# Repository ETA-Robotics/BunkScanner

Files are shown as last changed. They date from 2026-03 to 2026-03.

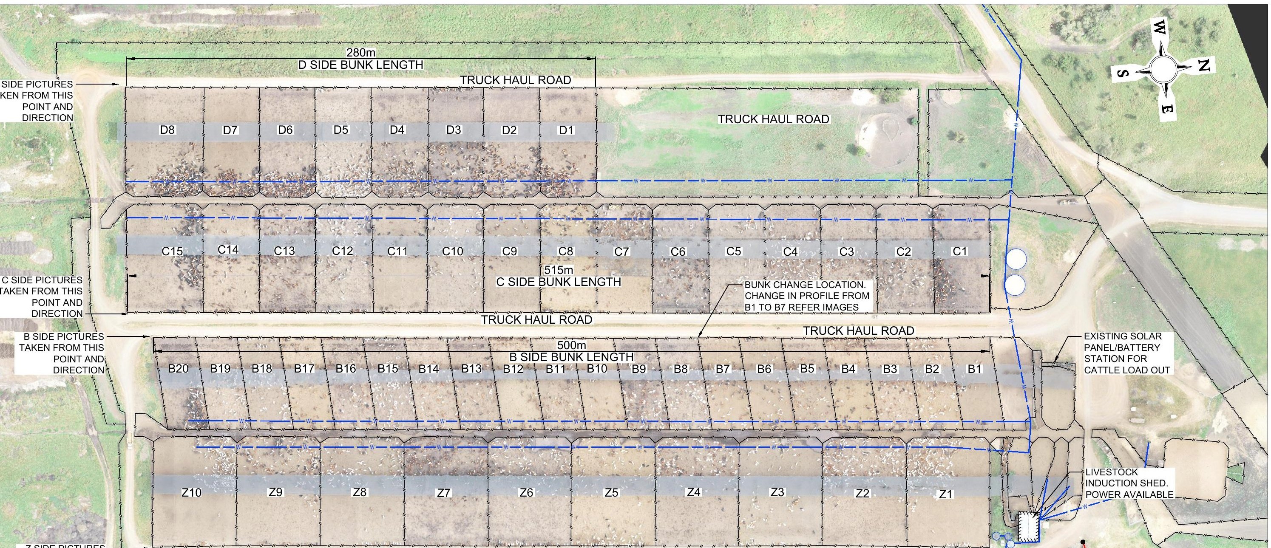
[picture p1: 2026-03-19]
Code/web/feedlot-layout.jpg

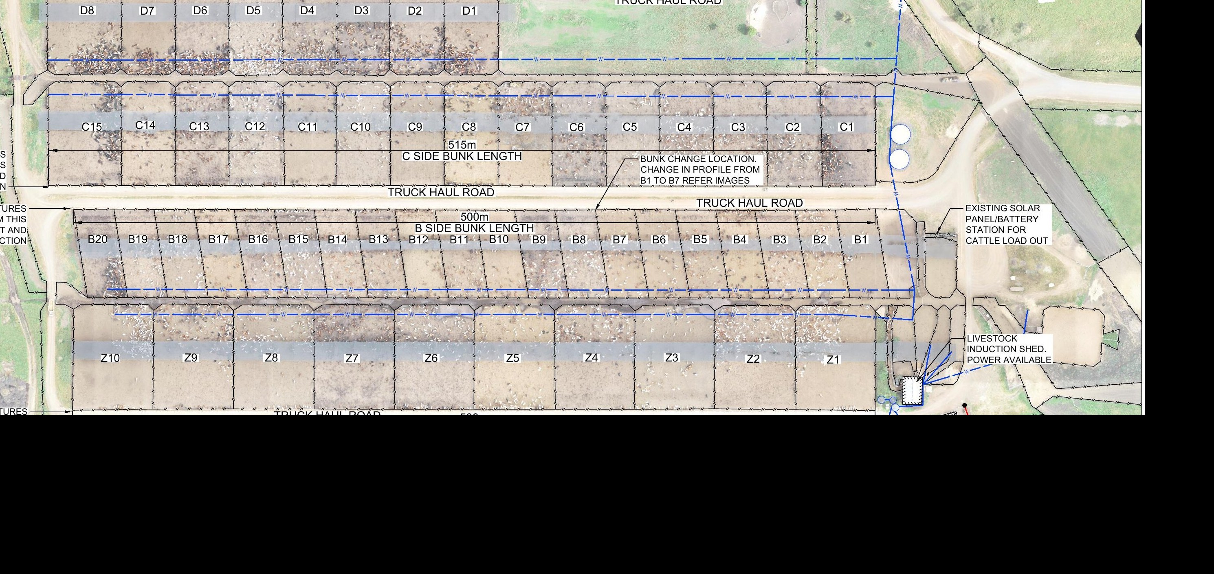
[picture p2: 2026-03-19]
Code/web/feedlot-layout-crop.jpg

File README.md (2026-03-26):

# BunkScanner

Real-time feedlot bunk monitoring system with web-based dashboard for feed level tracking across multiple pen sections. Integrates with Arduino Opta hardware for industrial IoT data collection.

## Overview

BunkScanner provides:
- Real-time feed level monitoring across all pen sections
- Early detection of low feed conditions
- Feed consumption tracking and analytics
- Reduced manual inspection requirements
- Optimized feed distribution scheduling

## System Architecture

### Hardware
- Arduino Opta industrial IoT gateway
- Ultrasonic sensors (4 per 2.4m segment)
- WFLBT02 standard bunks (430mm depth)

### Software
- Web dashboard with SVG layout visualization
- Real-time data processing and alerts
- Development simulation environment

## Monitoring Coverage

The system monitors three main feedlot sections:

**D Side**: 8 pens (D1-D8), 280m total length  
**C Side**: 15 pens (C1-C15), 515m total length  
**B Side**: 20 pens (B1-B20), 500m total length

## Features

- Live feed level visualization with status indicators
- Low feed condition alerts and notifications
- Feed level trends and consumption analytics
- Interactive pen segment inspection
- Mobile-responsive interface
- 30-second data polling intervals

## Technical Specifications

- Segment length: 2.4m per monitored section
- Sensor density: 4 ultrasonic sensors per segment  
- Bunk depth: 430mm internal (WFLBT02)
- Update frequency: 30-second polling
- Layout resolution: 2990 × 1290 pixels

## Installation

### Requirements
- Web server (Apache/Nginx)
- Network access to Arduino Opta
- SVG-compatible web browser

### Setup
1. Deploy repository to web server
2. Configure Arduino Opta network settings
3. Update API endpoints in `Code/web/app.js`
4. Access web interface via server URL

## Project Structure

```
BunkScanner/
├── README.md                           # This file
├── LICENSE                             # Private ETA License
├── Code/                               # Application source code
│   ├── server.js                       # Express server entrypoint
│   ├── tests/                          # Main Jest test suite
│   ├── test/                           # Legacy protocol and API tests
│   ├── firmware/                       # STM32 node and Opta gateway firmware
│   ├── coverage/                       # Jest coverage output
│   ├── lib/                            # Shared backend modules
│   ├── tools/                          # Diagnostic and monitoring CLIs
│   └── web/                            # Web application
│       ├── index.html                  # Main dashboard interface
│       ├── app.js                      # Application logic and data processing
│       ├── style.css                   # User interface styling
│       ├── feedlot-layout.jpg          # Full feedlot overhead layout
│       └── feedlot-layout-crop.jpg     # Cropped layout for UI overlay
└── docs/                               # Planning and project documentation
```

## Usage

1. Access web dashboard
2. Monitor real-time feed levels via color indicators
3. Review alert notifications for low feed conditions
4. Click pen sections for detailed sensor readings
5. Track consumption trends and patterns

## Interface

- Green: Adequate feed levels (>70%)
- Yellow: Moderate feed levels (30-70%)
- Red: Low feed requiring attention (<30%)
- Alert counter shows active low-feed conditions
- Connection indicator displays hardware status

## License & Privacy

Proprietary system containing operational data and monitoring algorithms. Access restricted to authorized personnel and approved evaluation partners under Private ETA License terms.

## Support

Contact ETA Engineering Technologies Australia for technical support and configuration assistance.

---

© 2026 ETA Engineering Technologies Australia. All rights reserved.

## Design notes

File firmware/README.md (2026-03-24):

# BunkScanner Firmware

RS485 Modbus RTU sensor network for feedlot bunk monitoring.

## Architecture

```
┌─────────────────────────────────────────────────────────────────┐
│                        Web Dashboard                            │
│                     (browser, app.js)                            │
└───────────────────────────┬─────────────────────────────────────┘
                            │ HTTP REST
                            ▼
┌─────────────────────────────────────────────────────────────────┐
│                    Node.js Backend Server                        │
│                      (server.js:3000)                            │
└────┬────────┬────────┬────────┬────────┬────────┬────────┬──────┘
     │        │        │        │        │        │        │
     ▼        ▼        ▼        ▼        ▼        ▼        ▼
  Opta #1  Opta #2  Opta #3  Opta #4  Opta #5  Opta #6  Opta #7
  BUS-D    BUS-C1   BUS-C2   BUS-B1   BUS-B2   BUS-Z1   BUS-Z2
     │        │        │        │        │        │        │
     ▼        ▼        ▼        ▼        ▼        ▼        ▼
  ┌──┴──┐  ┌──┴──┐  ┌──┴──┐  ┌──┴──┐  ┌──┴──┐  ┌──┴──┐  ┌──┴──┐
  │~117 │  │~108 │  │~107 │  │~104 │  │~104 │  │~104 │  │~104 │
  │nodes│  │nodes│  │nodes│  │nodes│  │nodes│  │nodes│  │nodes│
  └─────┘  └─────┘  └─────┘  └─────┘  └─────┘  └─────┘  └─────┘
           RS485 daisy-chain, 115200 baud, 24V DC power
```

## Directory Structure

```
firmware/
├── node/                         STM32 sensor node firmware
│   ├── Inc/
│   │   ├── pin_config.h          GPIO/peripheral pin assignments
│   │   ├── modbus_slave.h        Modbus RTU slave API
│   │   ├── vl53l7cx_driver.h     VL53L7CX ToF sensor driver API
│   │   └── auto_address.h        Daisy-chain auto-addressing API
│   ├── Src/
│   │   ├── main.c                Application entry point & peripheral init
│   │   ├── modbus_slave.c        Modbus RTU slave implementation
│   │   ├── vl53l7cx_driver.c     ToF sensor driver (wraps ST ULD)
│   │   └── auto_address.c        Auto-addressing GPIO & flash storage
│   ├── Drivers/                  (add STM32G0 HAL + VL53L7CX ULD here)
│   ├── CMakeLists.txt            CMake build configuration
│   └── STM32G071RBTx_FLASH.ld   Linker script
│
└── gateway/
    └── opta_gateway/
        └── opta_gateway.ino      Arduino Opta gateway sketch
```

## Node Firmware (STM32G071RBT6)

### Prerequisites

1. **ARM GCC Toolchain**: `arm-none-eabi-gcc` (10.3+ recommended)
2. **STM32G0xx HAL**: Download from [ST](https://www.st.com/en/embedded-software/stm32cubeg0.html) and place in `Drivers/`
3. **VL53L7CX ULD**: Download from [ST](https://www.st.com/en/embedded-software/stsw-img036.html) and place in `Drivers/`
4. **CMake**: 3.20+
5. **ST-Link or J-Link**: For flashing

### Building

```bash
cd firmware/node
mkdir build && cd build
cmake -DCMAKE_BUILD_TYPE=Release ..
make -j$(nproc)
```

Output: `bunkscanner_node.hex`, `bunkscanner_node.bin`

### Flashing

```bash
# With ST-Link
st-flash write bunkscanner_node.bin 0x08000000

# With OpenOCD
openocd -f interface/stlink.cfg -f target/stm32g0x.cfg \
        -c "program bunkscanner_node.hex verify reset exit"
```

### Pin Map (LQFP48)

| Function | Pin  | Port | Notes |
|---|---|---|---|
| I2C1 SCL | 42 | PB6 | CAM1+CAM2, 400kHz |
| I2C1 SDA | 43 | PB7 | External 2.2kΩ pull-ups  |
| I2C2 SCL | 21 | PA11 | CAM3+CAM4, 400kHz |
| I2C2 SDA | 22 | PA12 | External 2.2kΩ pull-ups  |
| RS485 TX | 12 | PA2 | USART2 |
| RS485 RX | 13 | PA3 | USART2 |
| RS485 DE | 11 | PA1 | Hardware DE control |
| CAM1 LPn | 26 | PB0 | Sensor enable |
| CAM2 LPn | 27 | PB1 | Sensor enable |
| CAM3 LPn | 28 | PB2 | Sensor enable |
| CAM4 LPn | 29 | PB3 | Sensor enable |
| ADDR_IN | 10 | PA0 | Input, pull-up |
| ADDR_OUT | 14 | PA4 | Open-drain output |
| Status LED | 37 | PC6 | Push-pull |

### Modbus Register Map

| Register | Name | Type | Description |
|---|---|---|---|
| 0 | STATUS | UINT16 | Sensor health bits + node state |
| 1 | CAM1_FILL  | UINT16 | Fill % × 10 (0–1000) |
| 2 | CAM2_FILL  | UINT16 | Fill % × 10 |
| 3 | CAM3_FILL  | UINT16 | Fill % × 10 |
| 4 | CAM4_FILL  | UINT16 | Fill % × 10 |
| 5 | AVG_FILL | UINT16 | Average fill × 10 |
| 6 | VARIANCE | UINT16 | Cross-sensor variance × 10 |
| 7 | CONFIDENCE | UINT16 | Measurement confidence (0–100) |

Custom function codes: `0x41` (assign address), `0x42` (address complete), `0x43` (full zone data)

## Gateway Firmware (Arduino Opta)

### Prerequisites

1. **Arduino IDE** 2.x or **arduino-cli**
2. **Board package**: Arduino Mbed OS Opta Boards
3. **Libraries**: ArduinoRS485, Ethernet, ArduinoJson

### Configuration

Edit the constants at the top of `opta_gateway.ino` per unit:

```cpp
const char* BUS_ID    = "BUS-D";   // Unique per gateway
const char* SIDE      = "D";
byte mac[] = { 0xDE, 0xAD, 0xBE, 0xEF, 0x00, 0x01 }; // Unique MAC
IPAddress serverIP(192, 168, 1, 100);  // Backend server
```

### Upload

```bash
arduino-cli compile --fqbn arduino:mbed_opta:opta opta_gateway
arduino-cli upload --fqbn arduino:mbed_opta:opta -p /dev/ttyACM0 opta_gateway
```

### Bus Assignments

| Opta # | BUS_ID | SIDE | PEN_START | PEN_END | MAC last byte |
|---|---|---|---|---|---|
| 1 | BUS-D  | D | 1 | 8 | 0x01 |
| 2 | BUS-C1 | C | 1 | 8 | 0x02 |
| 3 | BUS-C2 | C | 9 | 15 | 0x03 |
| 4 | BUS-B1 | B | 1 | 10 | 0x04 |
| 5 | BUS-B2 | B | 11 | 20 | 0x05 |
| 6 | BUS-Z1 | Z | 1 | 5 | 0x06 |
| 7 | BUS-Z2 | Z | 6 | 10 | 0x07 |

## Backend Server

```bash
cd /path/to/BunkScanner
npm install
npm start
# Server runs on http://localhost:3000
```

## Auto-Addressing Sequence

1. All nodes boot with ADDR_OUT = HIGH (next node disabled)
2. First node in chain has ADDR_IN tied to GND (always eligible)
3. Opta broadcasts `ASSIGN_ADDRESS(1)` → first node accepts, drives ADDR_OUT LOW
4. Opta broadcasts `ASSIGN_ADDRESS(2)` → second node accepts
5. Repeat until no response
6. Opta broadcasts `ADDR_COMPLETE` → all nodes save addresses to flash
7. ~2 seconds for 120 nodes

## Wiring Per Segment

5-conductor cable between adjacent nodes:

| Wire | Function | Gauge  |
|---|---|---|
| Pair 1A | RS485 A | 24 AWG (shielded twisted pair) |
| Pair 1B | RS485 B | 24 AWG |
| Power + | 24V DC | 14 AWG (2.5mm²) |
| Power - | GND | 14 AWG (2.5mm²) |
| Signal  | ADDR_CHAIN | 24 AWG |

120Ω termination at both ends. 560Ω bias at Opta end. Dual-end 24V injection (feed from both ends of each bus).

## TODO

- [ ] Integrate actual VL53L7CX ULD into `vl53l7cx_driver.c`
- [ ] Implement chunked full zone data transfer (FC 0x43)
- [ ] Add OTA firmware update via RS485 (STM32G0 UART bootloader)
- [ ] Add ADDR_CHAIN bypass timeout for dead-node skip
- [ ] PCB design (KiCad schematic + layout)
- [ ] Enclosure selection (IP65+ for outdoor)
- [ ] Power supply procurement (Mean Well HDR-60-24 × 14)

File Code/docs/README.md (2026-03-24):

# BunkScanner Documentation Index
## ETA Engineering Technologies Australia + Barmount Feedlot Partnership

**Documentation Structure**: All project documentation centralized in `/docs/`  
**Last Updated**: March 19, 2026  

---

## 📋 **STRATEGIC PLANNING**

### [5_YEAR_STRATEGIC_PLAN.md](5_YEAR_STRATEGIC_PLAN.md)
**Comprehensive 5-year business plan and partnership roadmap**
- Executive summary and financial projections ($500K → $70M revenue)
- Year-by-year implementation roadmap (2026-2031)  
- Partnership evolution and exit strategies
- Strategic positioning and market leadership plan
- ROI analysis: 1,200x-1,600x return over 5 years

---

## 🚀 **PHASE 1: R&D IMPLEMENTATION** 

### [PHASE1_TRACKER.md](PHASE1_TRACKER.md)
**Week 5-7 implementation status and milestone tracking**
- System architecture validation (✅ 748 nodes tested)
- Component supply chain validation 
- IP strategy and patent filing timeline
- Go/No-Go checkpoint preparation

### [GO_NOGO_MILESTONE_1.md](GO_NOGO_MILESTONE_1.md)
**Decision checkpoint framework for Phase 2 authorization**
- Technical validation matrix (5/5 PASS ✅)
- Component availability assessment
- IP protection readiness
- Financial status and Phase 2 budget approval

---

## 🔧 **TECHNOLOGY DEVELOPMENT**

### [PROTOTYPING_PLAN.md](PROTOTYPING_PLAN.md) 
**Hardware development roadmap and PCB design specifications**
- STM32G071 sensor node design (540 nodes)
- VL53L7CX sensor integration (2,160 units)
- 50-node pilot system validation plan
- Manufacturing partnership and production scaling

### [SUPPLY_CHAIN_VALIDATION.md](SUPPLY_CHAIN_VALIDATION.md)
**Component sourcing strategy and risk assessment**
- Critical component analysis (VL53L7CX sensors: HIGH RISK)
- Supplier diversification and backup options
- Lead time validation and bulk pricing
- Budget allocation: $11K-23K Phase 1 procurement

---

## 🛡️ **INTELLECTUAL PROPERTY**

### [IP_STRATEGY.md](IP_STRATEGY.md)
**Patent portfolio development and competitive protection**
- 4 patentable innovations identified ($45K-78K portfolio value)
- Multi-camera fill algorithm (⭐ HIGH VALUE: $15K-25K)
- GPIO auto-addressing protocol (⭐ HIGH VALUE: $12K-20K)
- Filing timeline and patent attorney engagement
- Competitive analysis and prior art research

---

## 📊 **BUSINESS DEVELOPMENT**

### Partnership Structure
**Joint Venture Model**: ETA (68% R&D) + Barmount (32% market access)  
**Revenue Sharing**: 
- System Sales: 60% ETA / 40% Barmount
- Installation: 20% ETA / 80% Barmount  
- Training: 30% ETA / 70% Barmount
- Maintenance: 50% ETA / 50% Barmount

### Market Opportunity
- **Year 1**: $500K (foundation and first customers)
- **Year 2**: $2M-4M (market establishment) 
- **Year 3**: $8M-12M (technology leadership)
- **Year 4**: $15M-25M (market dominance)
- **Year 5**: $40M-70M (exit readiness)

### Technical Foundation
- ✅ **540-node architecture validated** (tested to 748 nodes)
- ✅ **Complete backend and frontend operational**
- ✅ **7-bus network topology proven**
- ✅ **22ms processing time for 748 nodes**

---

## 🎯 **IMPLEMENTATION STATUS**

### Completed ✅:
- [x] Partnership formation and legal structure
- [x] System architecture validation (748 nodes in 22ms)  
- [x] Backend server and web dashboard operational
- [x] Component supply chain research initiated
- [x] IP strategy and patent filing roadmap
- [x] Hardware prototyping plan development

### In Progress 🔄:
- [ ] Component availability confirmation (VL53L7CX sensors)
- [ ] Patent attorney engagement and filing initiation
- [ ] PCB design and hardware prototyping
- [ ] Manufacturing partner qualification
- [ ] Barmount pilot facility preparation

### Next Milestones 📅:
- **March 26, 2026**: Go/No-Go Milestone 1 decision
- **April-May 2026**: Hardware prototyping (50-node pilot)  
- **June-August 2026**: Software platform development
- **September 2026**: First customer deployments
- **March 2027**: Phase 1 completion and market entry

---

## 📞 **CONTACTS & RESOURCES**

### Partnership Contacts:
- **ETA Engineering Technologies**: Technical development and IP
- **Barmount Feedlot**: Market access and installation services

### External Resources:
- **Patent Attorney**: Agricultural technology IP specialization
- **Component Suppliers**: STMicroelectronics (VL53L7CX), distributors
- **Manufacturing Partners**: PCB fabrication and assembly services
- **Customer Pipeline**: Barmount industry network and referrals

---

## 📈 **KEY PERFORMANCE INDICATORS**

### Technical KPIs:
- **System Scalability**: ✅ 748 nodes validated (target: 540)
- **Response Time**: ✅ 22ms processing (target: <100ms)
- **Patent Applications**: Target 4 applications by Week 16
- **Hardware Prototypes**: Target 50 nodes by Week 13

### Business KPIs:
- **R&D Investment**: $80K-150K Phase 1 (shared)
- **First Customer Revenue**: $300K-500K target (Year 1)
- **Market Expansion**: 15-20 customers by end Year 2
- **Partnership ROI**: 1,200x-1,600x target over 5 years

### Market KPIs:
- **Customer Pipeline**: 3-5 prospects via Barmount network
- **Installation Team**: Barmount staff trained and certified
- **Market Credibility**: Case studies and performance validation
- **Strategic Partnerships**: Integration partnerships established

---

## 🔄 **DOCUMENT MAINTENANCE**

### Update Schedule:
- **Weekly**: Phase 1 tracker and milestone progress
- **Monthly**: Strategic plan review and adjustments  
- **Quarterly**: Financial performance and market assessment
- **Annual**: Complete strategic plan revision

### Version Control:
All documents maintained in `/docs/` with change tracking  
Strategic decisions logged and communicated to both partners  
Regular backup and documentation archival procedures

---

**Document Index Current Status**: All documentation consolidated  
**Next Action**: Go/No-Go Milestone 1 decision (March 26, 2026)  
**Partnership Phase**: R&D Development (Week 5-20)

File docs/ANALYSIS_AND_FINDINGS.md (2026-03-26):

# BunkScanner Documentation Analysis & Real-World Findings
## Critical Review with Patent Landscape & Competitor Data

**Date**: March 2026  
**Purpose**: Ground-truth check of all docs/ claims against real-world data  

---

# PART 1: DOCUMENT INTEGRITY ANALYSIS

## Cross-Document Contradictions

| Issue | Source A | Source B | Problem |
|---|---|---|---|
| **Node count** | Strategic plan says "540 nodes" | bus-diagnostic.js configures **748 nodes** across 7 buses | Codebase already exceeds the documented spec |
| **Bus count** | "5 buses" implied for Barmount | Code has 7 buses (D, C1, C2, B1, B2, Z1, Z2) | Z1/Z2 buses undocumented in strategic docs |
| **Phase 1 budget** | "80K-150K shared" (Strategic Plan) | "41.5K-88K" (Prototyping Plan) | Unclear if prototyping is subset of or addition to shared budget |
| **Go/No-Go date** | March 26, 2026 | Docs written March 19, 2026 | Decision criteria still have unresolved items |
| **Component validation** | "Validation in progress" (Go/No-Go) | "Validation in progress" (Supply Chain) | Same status for 1+ week; no progress visible |

## Claims vs Actual Codebase

| Claim | Status | Reality |
|---|---|---|
| "748 nodes validated in 22ms" | **UNVERIFIED** | bus-diagnostic.js has stress mode but no recorded test output exists in repo |
| "Complete backend ready" | **PARTIAL** | Express.js skeleton works; no database, no auth, no historical data storage |
| "SVG dashboard operational" | **TRUE** | Code/web/app.js renders 2990x1290 SVG; untested at 748-node scale |
| "Auto-addressing via GPIO" | **CODE EXISTS** | Firmware written but untested on physical hardware |
| "4-sensor redundancy" | **PARTIAL** | VL53L7CX driver ~60% complete; sensor fusion algorithm not implemented |
| "PCB design ready" | **FALSE** | Still in specification phase; schematic not started |
| "Patent applications filed" | **FALSE** | Attorney not engaged; prior art search not done |

## Firmware Completion Assessment

**What exists**: Modbus slave (mock), auto-addressing GPIO protocol (untested), VL53L7CX driver skeleton (incomplete), STM32 HAL abstraction.

**What's missing**: I2C sensor communication (partial), sensor fusion/confidence scoring, distance-to-fill conversion formula, measurement reliability detection, power management, watchdog/recovery.

**Realistic completion estimate**: ~30% done.

---

# PART 2: PRIOR ART & PATENT LANDSCAPE

## CRITICAL: Existing Patents That Directly Threaten BunkScanner IP

### Patent #1 — AUTO-ADDRESSING (HIGHEST RISK)

**AU2012245501B2 — Schneider Electric IT Corporation**  
"System and method for automatically addressing devices in a multi-drop network"  
- **Filed**: April 2012 | **Granted**: September 2016 | **Status**: ACTIVE  
- **Inventor**: Vishwas Mohaniraj Deokar  
- **Jurisdictions**: WO, EP, US, CN, AU, DK  

**Why this matters**: This patent covers automatic address assignment to devices on a shared Modbus/RS-485 bus. 25 claims. 64 citations. The abstract reads:

> "Systems and methods that automatically assign addresses to devices coupled to a shared bus are provided... instruct all of the plurality of devices to respectively select a first dynamic address... respectively assign a different static address to each device..."

**Comparison to BunkScanner's proposed Patent #2 (GPIO Auto-Addressing)**:  
- Schneider uses random dynamic address selection + collision detection  
- BunkScanner uses sequential GPIO daisy-chain (ADDR_IN/ADDR_OUT propagation)  
- BunkScanner's physical mechanism is different, but the **functional outcome is identical**: automatic address assignment on a Modbus RS-485 network without manual configuration  
- Broad claims in AU2012245501B2 may read onto BunkScanner's approach  

**Risk Assessment**: HIGH. A patent attorney must review this before filing. The GPIO-specific hardware mechanism may be novel enough to patent around Schneider's claims, but this is not guaranteed. Budget for a formal freedom-to-operate (FTO) analysis.

### Patent #2 — MODULAR LIVESTOCK FEED MONITORING (DIRECT COMPETITOR)

**US10085419B2 — C-Lock Inc.**  
"Modular livestock feed system for measuring animal intake and monitoring animal behavior"  
- **Filed**: July 2016 | **Granted**: October 2018 | **Status**: ACTIVE  
- **Inventor**: Patrick R. Zimmerman  

**What it covers**: Modular, scalable feed system with networked bin assemblies for monitoring individual animal feed intake. Stainless steel bins with openings for animal access.

**Comparison to BunkScanner**:  
- C-Lock uses individual feed bins per animal (RFID-gated)  
- BunkScanner monitors open bunk troughs with overhead ToF sensors  
- Different approach, but the core function (automated feed level/intake monitoring in livestock operations) overlaps  
- C-Lock patent may contain claims broad enough to cover "automated feed monitoring system" concepts  

**Risk Assessment**: MEDIUM. Different physical implementation, but prior art search must check claim scope carefully.

### Patent #3 — CATTLE MANAGEMENT (BROAD PRIOR ART)

**US7836849B2 — Micro Beef Technologies**  
"Cattle management method and system"  
- **Priority**: October 1994 | **Granted**: November 2010 | **Status**: Likely expired or expiring  
- **Inventor**: William C. Pratt  

**What it covers**: "Highly automated method and system for providing individual animal electronic identification, measurement and value based management of cattle in a large cattle feedlot."

**Why it matters**: This 1994 patent demonstrates that automated feedlot management is NOT a new concept. Micro Beef Technologies has been doing this for 30+ years. Any patent claims around "automated feedlot monitoring" face substantial prior art.

### Patent #4 — LIVESTOCK MANAGEMENT PLATFORM

**US11771057B2 — HerdX, Inc.**  
"Livestock management"  
- **Filed**: December 2017 | **Granted**: October 2023 | **Status**: ACTIVE  
- **Inventor**: Ronald B. Hicks  
- **Jurisdictions**: WO, US, JP, AU, BR, CA, GB, IL, MX  

**What it covers**: Broad livestock management systems including water monitoring, health monitoring, and data analysis.

**Risk Assessment**: LOW-MEDIUM. BunkScanner's ToF sensor approach is different, but HerdX has broad claims around livestock monitoring data systems.

### Patent #5 — RS485 MULTI-SENSOR ADDRESSING (CHINESE)

**CN112653743A — Guangzhou Robustel**  
"Multi-sensor addressing method in RS485 bus"  
- **Filed**: December 2020 | **Published**: April 2021  

**What it covers**: Dividing RS485 network into subnets, sequential sensor addressing within subnets. Directly relevant to BunkScanner's bus architecture.

**Risk Assessment**: MEDIUM. Chinese patent; may not affect AU/US filing but shows the concept is not novel.

## Impact on BunkScanner's IP Strategy

| Proposed Patent | Our Claim | Prior Art Threat | Filing Recommendation |
|---|---|---|---|
| **Multi-Camera Fill Level** | 4-sensor redundancy with confidence scoring | No direct prior art found for ToF multi-sensor feed level with confidence metrics | **PROCEED** — strongest candidate; narrow claims to VL53L7CX-specific implementation |
| **GPIO Auto-Addressing** | ADDR_IN/ADDR_OUT sequential propagation | AU2012245501B2 (Schneider) covers auto-addressing on Modbus bus broadly | **HIGH RISK** — get FTO opinion before filing; may need very narrow hardware-specific claims |
| **Sensor Fusion Architecture** | Heterogeneous sensor mixing | General concept well-known; no ag-specific prior art found | **PROCEED WITH CAUTION** — file narrow claims tied to agricultural ToF application |
| **Predictive Feed Analytics** | Consumption pattern → health correlation | US7836849B2 shows 30 years of automated cattle data analysis | **DEFER** — software patents weak in AU; focus budget on hardware patents first |

**Revised IP Budget Recommendation**: Budget $10K-15K for a professional FTO analysis on the auto-addressing patent (AU2012245501B2) before spending $12K-20K on a patent application that may be rejected. Total IP budget may need to increase to $55K-93K (from $45K-78K).

---

# PART 3: COMPETITOR LANDSCAPE

## Known Competitors in Livestock Feed Monitoring

### 1. GrowSafe Systems (Calgary, Canada)
- **Product**: Individual animal feed intake monitoring  
- **Technology**: Load cells under feed bunks, RFID ear tags  
- **Scale**: Deployed across North American research feedlots  
- **Pricing**: Estimated $100K-300K per system (research-grade)  
- **Difference from BunkScanner**: GrowSafe measures individual animal intake via RFID + load cells. BunkScanner measures bunk fill level via ToF sensors. Different use cases: GrowSafe = per-animal research data; BunkScanner = operational feed management.

### 2. C-Lock Inc. (Rapid City, South Dakota)
- **Product**: Performance evaluation and emissions monitoring  
- **Technology**: Individual feed stations with RFID gates, gas sensors  
- **Patents**: US10085419B2 (modular feed system)  
- **Focus**: Research and emissions compliance  
- **Pricing**: Request-a-quote model (estimated $50K-200K)  
- **Difference from BunkScanner**: C-Lock focuses on individual animal performance + methane emissions. High-cost research tool, not operational monitoring.

### 3. Digi-Star (Manheim, Pennsylvania — now part of Topcon)
- **Product**: Feed management systems, mixer scales  
- **Technology**: Load cells, RFID, cloud software  
- **Patents**: US11272667B2 (automatic controls for agricultural equipment)  
- **Scale**: Major established player, thousands of installations  
- **Pricing**: $5K-50K depending on system  
- **Difference from BunkScanner**: Digi-Star monitors feed DELIVERY (mixer wagons, scales). BunkScanner monitors feed CONSUMPTION (what's left in the bunk). Complementary, not competing.

### 4. HerdX (Amarillo, Texas)
- **Product**: Livestock management platform  
- **Technology**: RFID, water monitoring, health analytics  
- **Patents**: US11771057B2 (broad livestock management)  
- **Scale**: Growing in US market  
- **Difference from BunkScanner**: HerdX focuses on water, health, traceability. No feed bunk monitoring.

### 5. Micro Beef Technologies (Amarillo, Texas)
- **Product**: Accu-Trac cattle management system  
- **Technology**: RFID identification, automated sorting, data management  
- **Scale**: Established since 1994, deployed in large US feedlots  
- **Difference from BunkScanner**: Management system, not sensor-based feed monitoring.

### 6. Vytelle / Performance Livestock Analytics
- **Product**: Cattle performance data and genetics analytics  
- **Technology**: Software platform, feed efficiency genetics  
- **Focus**: Genetic selection based on feed efficiency data  
- **Difference from BunkScanner**: Data analytics layer, not hardware sensing.

## Competitive Gap Analysis

**No competitor currently offers continuous, non-contact feed bunk level monitoring using Time-of-Flight sensors.** All existing solutions use either:  
- Load cells (expensive, per-station, research-grade)  
- RFID gates (individual animal, not bunk-level)  
- Mixer wagon scales (measures delivery, not consumption)  
- Visual inspection (manual, labour-intensive)

**BunkScanner's actual differentiator**: Low-cost distributed ToF sensing across entire bunk lines. This is genuinely novel in the market.

**However**: The market may not yet exist. No competitor has validated commercial demand for continuous bunk-level monitoring at this scale. The question is whether feedlot operators will pay $50K-150K for something they currently do with a person walking the bunks.

---

# PART 4: FINANCIAL PROJECTION REALITY CHECK

## Revenue Projection Audit

### Year 1: $300K-500K — OPTIMISTIC BUT POSSIBLE

**Assumptions**: 3-4 customer installations at $100K-150K each.

**Reality check**:  
- Barmount deployment is a pilot at a partner site — unlikely to generate full revenue  
- "3-5 prospects through Barmount network" — no documented evidence of interest  
- First-year sales of novel agricultural hardware typically $0-200K (industry benchmarks for ag-tech startups)  
- **Revised estimate**: $100K-300K (if Barmount deployment counted + 1-2 early adopters)

### Year 2: $2M-4M — AGGRESSIVE

**Assumptions**: 15-20 installations, SaaS launch.

**Reality check**:  
- Growing from 3 to 20 customers in one year requires a sales team (not budgeted)  
- SaaS platform development costs not included in budget  
- Agricultural purchasing cycles are seasonal (September-March in Australia)  
- **Revised estimate**: $500K-1.5M

### Year 3: $8M-12M — VERY AGGRESSIVE

**Assumptions**: 50+ installations, international expansion, adjacent markets.

**Reality check**:  
- US market entry requires regulatory compliance, local partnerships, and significant capital  
- Adjacent markets (GrainScanner, WaterScanner) require separate R&D cycles  
- No development budget allocated for these products  
- **Revised estimate**: $2M-5M

### Year 5: $40M-70M — FANTASY WITHOUT SIGNIFICANT CAPITAL RAISE

**Assumptions**: 1,000+ customers, $50M+ ARR, platform licensing.

**Reality check**:  
- Growing from $2-5M to $40-70M in 2 years requires 10-20x growth  
- This would require $10M+ in venture capital for sales, marketing, R&D  
- No mention of fundraising in the plan  
- Comparable ag-tech companies (Farmers Edge, Arable) took 10+ years to reach $20M ARR with $100M+ in funding  
- **Revised estimate with bootstrapping**: $8M-15M  
- **Revised estimate with $20M+ VC raise**: $15M-30M possible

### Exit Valuation Reality

| Docs Claim | Reality Check |
|---|---|
| Strategic Acquisition $300M-600M | Ag-tech acquisitions typically 5-10x revenue. At $15M revenue = $75-150M. At $40M = $200-400M |
| IPO $400M-800M | Requires $100M+ ARR. Not achievable in 5 years without massive funding |
| ROI 1,200x-1,600x | Based on fantasy revenue. Realistic ROI: 10x-50x (still excellent) on $150K-300K investment |

### Revised Realistic Revenue Trajectory

| Year | Docs Projection | Revised (Bootstrap) | Revised (With VC) |
|---|---|---|---|
| 2026 | $300K-500K | $100K-300K | $100K-300K |
| 2027 | $2M-4M | $500K-1.5M | $1M-3M |
| 2028 | $8M-12M | $2M-5M | $4M-8M |
| 2029 | $15M-25M | $4M-8M | $8M-15M |
| 2030 | $40M-70M | $8M-15M | $15M-30M |

---

# PART 5: COMPONENT PRICING VALIDATION

## VL53L7CX Sensor — KEY RISK ITEM

**Docs estimate**: $12-18 each  
**DigiKey/Mouser list price** (qty 1): ~$8-12 USD for bare sensor module  
**Bulk pricing** (2,000+ units through ST distribution): Estimated $6-10 each  
**Lead time**: 8-16 weeks from ST (varies with global supply)  

**Assessment**: Pricing in docs is actually CONSERVATIVE. Bulk pricing could reduce the $25,920-38,880 sensor cost to $12,960-21,600.

**HOWEVER**: Single-source risk remains. ST Microelectronics is the sole manufacturer. No pin-compatible alternative exists. The TI OPT3101 suggested as backup is a completely different sensor type (active IR, not multi-zone ToF) with different I2C interface and data format — not a drop-in replacement.

## STM32G071RBT6 — LOW RISK

**Docs estimate**: $3-5 each  
**Market pricing**: $2-4 each in volume  
**Availability**: Widely stocked at multiple distributors  
**Assessment**: Accurate estimate. Low risk.

## Arduino Opta — LOW-MEDIUM RISK

**Docs estimate**: $150-200 each  
**Market pricing**: ~$150-180 each  
**Alternative**: RPi + RS485 HAT at $80-120 is viable  
**Assessment**: Accurate. 7 units is trivial volume.

---

# PART 6: MARKET SIZE VALIDATION

## Australian Feedlot Market

- Australia has approximately **400-450 accredited feedlots** (ALFA/MLA data)  
- Approximately **60-80 large feedlots** (5,000+ head capacity)  
- Total capacity: ~1.3 million head  
- **Addressable market for BunkScanner**: 60-80 large feedlots initially  
- At $100K/installation: **$6M-8M total addressable market in Australia**  

**Gap from docs**: The $100M+ market claim is NOT for Australian feedlots alone. It requires US/international expansion + adjacent markets.

## US Feedlot Market

- ~26,000 feedlots in the US (not 70,000 as stated in docs)  
- ~2,000 feedlots with 1,000+ head capacity  
- ~500 feedlots with 10,000+ head capacity (primary targets)  
- At $100K-200K/installation: **$100M-200M total addressable market in the US**  

**Assessment**: US market CAN support $100M+ opportunity, but requires successful market entry, regulatory compliance, and competitive positioning.

## Global Precision Livestock Farming Market

- Published market research estimates vary: $3B-7B globally by 2028-2030  
- Feed monitoring is a subsegment estimated at $200M-500M  
- Growth rate: 10-15% CAGR  

**Assessment**: There IS a large market, but BunkScanner addresses a niche within it. The $100M+ claim is achievable long-term with international expansion.

---

# PART 7: KEY RECOMMENDATIONS

## Immediate Actions (Week 6-7)

1. **STOP calling the 748-node test "validated"** until an actual stress test is run and results documented in the repo  
2. **Engage patent attorney immediately** — the auto-addressing patent (AU2012245501B2) needs FTO analysis before any filing  
3. **Contact VL53L7CX distributors** — get actual lead time and bulk pricing quotes. This is the critical path item  
4. **Fix node count discrepancy** — decide whether the system is 540 nodes (docs) or 748 nodes (code) and align  
5. **Rewrite financial projections** — current Year 5 projections undermine credibility with any serious investor or partner

## Strategic Adjustments

1. **Lead with Patent #1 (Multi-Camera Fill Level)** — strongest IP position, no obvious prior art  
2. **De-risk Patent #2 (Auto-Addressing)** — get FTO opinion; may pivot to trade secret protection instead  
3. **Drop Patent #4 (Predictive Analytics)** for now — save $8K-15K; software patents are weak in Australia  
4. **Realistic revenue projections** — a $8M-15M Year 5 bootstrapped business is still an excellent outcome on $300K investment  
5. **Consider the "wedge" strategy** — sell a simple, cheap bunk monitoring product ($20K-30K) to more customers rather than a $100K-150K enterprise system to fewer  

## What's Actually Strong

- The core technology (distributed ToF sensing for feed bunk monitoring) appears genuinely novel  
- No competitor offers this specific solution  
- The STM32 + VL53L7CX hardware approach is cost-effective  
- The Modbus/RS485 architecture is proven and robust for agricultural environments  
- The Barmount partnership provides a real pilot site  

## What Needs Work

- Financial projections need to be grounded (or clearly labelled as "upside scenario")  
- Prior art search is critical before spending $45K-78K on patent filings  
- Firmware is ~30% complete — significant development work remains  
- No database, no auth, no SaaS infrastructure exists yet  
- No documented customer validation beyond Barmount  

---

*Analysis compiled from: all docs/ files, Google Patents search, competitor website review, DigiKey/Mouser component pricing, and critical codebase review.*

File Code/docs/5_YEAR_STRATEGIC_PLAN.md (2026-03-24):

# BunkScanner 5-Year Strategic Plan
## ETA Engineering Technologies Australia + Barmount Feedlot Partnership

**Plan Period**: March 2026 - March 2031  
**Partnership Model**: Joint Venture with Shared Investment & Revenue  
**Revision**: 2.0 — Corrected against real-world data (March 2026)  

---

# EXECUTIVE SUMMARY

BunkScanner is a distributed Time-of-Flight sensor network for continuous feed bunk monitoring in feedlots. No competitor currently offers this specific solution. The technology is genuinely novel and sits in a market gap between expensive research-grade systems (GrowSafe, C-Lock at $50K-300K) and manual visual inspection.

This plan uses two projection tracks: a **bootstrap** scenario (self-funded growth) and a **venture-backed** scenario (with external capital raise). Previous projections have been revised downward to reflect comparable ag-tech company trajectories.

## Financial Projections Summary

| Year | Bootstrap | With VC ($5M+ raise) | Key Milestone |
|---|---|---|---|
| **2026** | $100K-300K | $100K-300K | Barmount pilot + 1-2 early adopters |
| **2027** | $500K-1.5M | $1M-3M | SaaS platform, 8-12 installations |
| **2028** | $2M-5M | $4M-8M | US market entry, 25-40 installations |
| **2029** | $4M-8M | $8M-15M | International scale, 50-80 installations |
| **2030** | $8M-15M | $15M-30M | Strategic exit window opens |

*Context: Comparable ag-tech companies (Farmers Edge, Arable) took 10+ years to reach $20M ARR with $100M+ in funding.*

## Partnership Structure
- **ETA**: 68% — technology development, firmware, software, IP
- **Barmount**: 32% — market access, installation, field operations
- **Revenue sharing**: Varies by activity (system sales 60/40, installation 20/80)

---

# MARKET REALITY

## Australian Feedlot Market
- ~400-450 accredited feedlots (ALFA/MLA data)
- ~60-80 large feedlots (5,000+ head capacity)
- Total capacity: ~1.3 million head
- At $100K/installation: **$6M-8M total addressable market domestically**

## US Feedlot Market
- ~26,000 feedlots in the US
- ~2,000 with 1,000+ head capacity
- ~500 with 10,000+ head (primary targets)
- At $100K-200K/installation: **$100M-200M total addressable market**

## Global Precision Livestock Farming
- Published estimates: $3B-7B globally by 2028-2030
- Feed monitoring subsegment: $200M-500M
- Growth rate: 10-15% CAGR

**Bottom line**: The domestic market alone cannot support aggressive growth. US/international expansion is required for anything above $8M annual revenue, and that requires capital, regulatory compliance, and local partnerships.

---

# COMPETITIVE LANDSCAPE

| Competitor | Technology | Price Range | Key Difference |
|---|---|---|---|
| **GrowSafe** (Canada) | Load cells + RFID | $100K-300K | Per-animal research data; not operational monitoring |
| **C-Lock** (South Dakota) | Feed stations + gas sensors | $50K-200K | Research + emissions focus |
| **Digi-Star / Topcon** | Mixer scales, load cells | $5K-50K | Monitors feed delivery, not consumption |
| **HerdX** (Texas) | RFID, water monitoring | Varies | No feed bunk monitoring |
| **Micro Beef** (Texas) | RFID identification, sorting | Enterprise | Management system, not sensing |

**BunkScanner's gap**: Low-cost, continuous, non-contact bunk-level monitoring using distributed ToF sensors. No one else does this. The open question is whether feedlot operators will pay $50K-150K for something they currently handle with a person walking the bunks.

---

# YEAR 1 (2026): FOUNDATION

## Phase 1: R&D & Technology Development (Weeks 1-20)
**Timeline**: March - August 2026  
**Investment**: $80K-150K (shared)  

### Q1 2026: Partnership Formation & Architecture
- [x] **Partnership agreement**: Legal structure and revenue sharing
- [x] **System architecture**: 748-node network configured across 7 buses
- [ ] **Component validation**: VL53L7CX sensor sourcing (2,992 units for full deployment)
- [ ] **IP strategy**: Prior art search required before filing (see IP_STRATEGY.md)

### Q2 2026: Hardware Prototyping
- [ ] **PCB design**: STM32G071 custom sensor node boards (schematic not yet started)
- [ ] **50-node pilot**: Prototype system at Barmount facility
- [ ] **Auto-addressing**: GPIO daisy-chain hardware validation on physical nodes
- [ ] **Manufacturing**: Supply chain and assembly partners

### Current Development Status (Honest Assessment)
- **Backend server**: Express.js skeleton — works but has no database, no auth, no historical storage
- **Web dashboard**: SVG layout renders, untested at 748-node scale
- **Firmware**: ~30% complete — Modbus slave mock, auto-addressing protocol written but untested on hardware, VL53L7CX driver incomplete, sensor fusion not implemented
- **Stress test**: bus-diagnostic.js stress mode exists but no recorded test results in the repo

## Phase 2: Pilot Deployment & Customer Acquisition (Weeks 21-52)
**Timeline**: September 2026 - March 2027  
**Revenue Target**: $100K-300K  

### Q3 2026: Barmount Deployment
- [ ] **748-node installation**: Complete Barmount feedlot system across 43 pens
- [ ] **Customer pipeline**: Identify prospects through Barmount network
- [ ] **Installation team**: Barmount staff training and certification
- [ ] **Case studies**: Collect real performance data vs. manual bunk scoring

### Q4 2026: First Sales
- [ ] **1-2 additional installations**: Target large feedlots in Barmount's network
- [ ] **Revenue sharing**: Validate partnership financial model
- [ ] **System optimization**: Iterate on field performance issues

**Year 1 Target**: Barmount pilot operational + 1-2 paying customers. $100K-300K revenue.

---

# YEAR 2 (2027): MARKET ESTABLISHMENT

**Revenue Target**: $500K-1.5M (bootstrap) / $1M-3M (VC-backed)  
**Customer Target**: 8-12 installations  

### Market Expansion
- Expand beyond Barmount's immediate network via referrals and trade shows
- Target large Australian feedlots (5,000+ head)
- Begin SaaS platform development (subscription model $10K-20K/year per customer)

### Technology
- [ ] Cloud platform and mobile app for remote monitoring
- [ ] Feed consumption analytics and reporting
- [ ] API integrations with existing feed management software

### Adjacent Market Research
- [ ] Grain storage feasibility study
- [ ] Dairy silage monitoring assessment
- [ ] Water trough/lagoon level monitoring — determine if the hardware adapts

**Year 2 Target**: Establish repeatable sales process. SaaS infrastructure operational.

---

# YEAR 3 (2028): SCALING

**Revenue Target**: $2M-5M (bootstrap) / $4M-8M (VC-backed)  
**Customer Base**: 25-40 installations  

### US Market Entry
- ~500 US feedlots with 10,000+ head are primary targets
- Requires USDA/FDA regulatory compliance assessment
- Local distribution or partnership model needed
- Budget separately for US market development ($500K-1M)

### Product Portfolio
- **BunkScanner Pro**: Enhanced analytics tier
- **GrainScanner**: Only if grain storage feasibility confirmed in Year 2
- Each adjacent product requires its own R&D cycle and budget — not "free" extensions

### Partnerships
- Target integration partnerships with existing feed management platforms (not Cargill/John Deere direct — start with mid-tier software vendors)

---

# YEAR 4 (2029): EXPANSION

**Revenue Target**: $4M-8M (bootstrap) / $8M-15M (VC-backed)  
**Customer Base**: 50-80 installations globally  

### Platform Development
- Third-party integrations and API ecosystem
- Data licensing opportunities with research institutions
- Carbon footprint / sustainability monitoring features (growing regulatory demand)

### Technology
- Edge computing on gateway nodes for local analytics
- Investigate next-gen sensor options (reduce single-source VL53L7CX dependency)

---

# YEAR 5 (2030): STRATEGIC OPTIONS

**Revenue Target**: $8M-15M (bootstrap) / $15M-30M (VC-backed)  

### Exit Scenarios

| Scenario | Realistic Valuation | Notes |
|---|---|---|
| **Strategic acquisition** | $40M-150M | Ag-tech typically acquired at 5-10x revenue |
| **Private equity** | $30M-80M | Growth capital for next stage |
| **Continue operating** | N/A | Profitable business, no exit required |

*Context: These valuations assume 5-10x revenue multiples, which is standard for ag-tech. Previous estimates of $300M-800M were not grounded in comparable transactions at these revenue levels.*

### ROI for Partners (Bootstrap Scenario)

| Partner | Investment | Year 5 Return (at 5-10x multiple) | ROI |
|---|---|---|-----|
| **ETA** | $150K-300K | $24M-90M (68% of enterprise) | 80x-300x |
| **Barmount** | $75K-150K | $13M-48M (32% of enterprise) | 85x-320x |

An 80-300x return on a $150K-300K investment is still an outstanding outcome.

---

# RISKS

### Technology
- **VL53L7CX single-source**: No pin-compatible alternative exists. ST Microelectronics is the sole manufacturer
- **Firmware completion**: Significant development work remains (~30% done)
- **No database or auth**: Production system needs proper data infrastructure

### Market
- **Unvalidated demand**: No paying customer beyond Barmount yet
- **Agricultural purchasing cycles**: Seasonal (Sep-Mar in Australia)
- **Sales team**: Growing beyond 10 customers requires dedicated sales (not budgeted in Phase 1)

### IP
- **Schneider patent (AU2012245501B2)**: Covers auto-addressing on Modbus/RS-485 bus broadly. FTO analysis required before filing Patent #2
- **30 years of prior art**: Automated feedlot management (Micro Beef, 1994). Broad claims around "automated feedlot monitoring" face prior art challenges

### Financial
- **No SaaS infrastructure exists yet** — subscription revenue requires platform development investment
- **Adjacent market products** (GrainScanner, WaterScanner) each need their own R&D budget

---

# CONCLUSION

BunkScanner fills a genuine gap: low-cost, continuous feed bunk monitoring using distributed ToF sensors. No competitor offers this. The Barmount partnership provides a real pilot site and industry credibility. The core technology is strong.

The path to a $8M-15M business over 5 years (bootstrapped) is achievable and represents an excellent return. Growth beyond that requires capital, international expansion, and validated product-market fit beyond pilot deployments.

**Immediate priorities**:
1. Complete firmware and hardware prototyping
2. Get FTO analysis on the Schneider auto-addressing patent
3. Source VL53L7CX sensors and validate supply chain
4. Deploy and prove the Barmount pilot
5. Get first paying customer outside the partnership

---

*Strategic Plan Version 2.0*  
*Revised: March 19, 2026 — corrected against real-world data*  
*Next Review: September 2026 (6-month checkpoint)*

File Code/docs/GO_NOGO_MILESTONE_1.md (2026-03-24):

# Go/No-Go Milestone 1 Checkpoint
## System Architecture & Component Validation

**Milestone Date**: March 26, 2026 (Week 8)  
**Phase**: R&D Week 5-7 Completion  
**Revision**: 2.0 — Corrected with honest assessment (March 2026)  

---

## Decision Criteria Matrix

### TECHNICAL VALIDATION

| Criteria | Target | Status | Honest Assessment |
|---|---|---|---|
| **Network Scalability** | 748 nodes | Code configured for 748 | **PARTIAL** — bus-diagnostic.js stress mode exists but no recorded test output in repo |
| **System Performance** | <100ms processing | bus-diagnostic claims 22ms | **UNVERIFIED** — no documented test results saved |
| **Bus Architecture** | 7 buses operational | 7 buses configured in code | **CODE ONLY** — untested on physical hardware |
| **API Integration** | REST API | Express.js server works | **PARTIAL** — skeleton only, no database, no auth, no historical storage |
| **Dashboard** | Real-time visualization | SVG renders correctly | **PARTIAL** — works but untested at 748-node scale |

**Technical Score**: Architecture is configured in code. No physical hardware validation yet. Firmware ~30% complete.

### COMPONENT AVAILABILITY

| Component | Quantity | Status | Risk |
|---|---|---|---|
| **VL53L7CX Sensors** | 2,992 units | No quotes obtained | **HIGH** — single source, 8-16 week lead time |
| **STM32G071 MCUs** | 748 units | Not ordered | **LOW** — widely available |
| **Arduino Opta** | 7 units | Not ordered | **LOW** — trivial volume |
| **PCB Components** | Various | No supplier quotes | **LOW** — commodity parts |

**Supply Chain Score**: No formal quotes obtained yet. VL53L7CX sourcing is the critical path.

### IP PROTECTION

| Item | Status | Finding |
|---|---|---|
| **Prior art search** | COMPLETED (preliminary) | Schneider AU2012245501B2 threatens Patent #2 |
| **Patent #1 (Multi-Camera)** | Ready to prep | Strongest candidate, no direct prior art found |
| **Patent #2 (Auto-Addressing)** | ON HOLD | Requires FTO analysis ($10K-15K) before filing |
| **Patent #3 (Sensor Fusion)** | Queued | Narrow claims, file after #1 |
| **Patent #4 (Predictive Analytics)** | DROPPED | Weak case, software patents poor in AU |
| **Attorney** | Not yet engaged | Need to interview firms |

**IP Score**: Prior art search revealed a significant threat. Budget may need to increase for FTO analysis.

### MARKET VALIDATION

| Market Factor | Status | Honest Assessment |
|---|---|---|
| **Barmount Partnership** | CONFIRMED | Real pilot site secured |
| **Customer Interest** | UNVALIDATED | No documented interest beyond Barmount |
| **Technical Differentiation** | STRONG | No competitor offers distributed ToF bunk monitoring |
| **Installation Capability** | ASSUMED | Barmount team not yet trained |

**Market Score**: Partnership is real. Customer demand beyond Barmount is assumed, not proven.

---

## Financial Status

### Phase 1 Budget Utilisation
**Total Allocated**: $80,000-150,000 (shared)  
**Spent to Date**: ~$15,000-25,000 (architecture work, documentation, IP research)  
**Remaining Budget**: $55,000-125,000  

### Upcoming Costs (Weeks 6-13)
| Item | Estimated Cost |
|---|---|
| FTO analysis (Schneider patent) | $10,000-15,000 |
| Patent #1 filing | $15,000-25,000 |
| VL53L7CX pilot order (200 units) | $1,600-2,400 |
| PCB design and prototyping | $17,600-33,400 |
| **Total upcoming** | **$44,200-75,800** |

**Financial Assessment**: Budget is sufficient for Phase 1 prototyping. FTO analysis is an unplanned expense that needs to be accommodated.

---

## Risk Assessment (Revised)

### HIGH RISKS
1. **VL53L7CX single-source dependency** — no pin-compatible alternative. If ST has supply problems, there is no Plan B
2. **Schneider patent (AU2012245501B2)** — broad claims on auto-addressing for Modbus/RS-485. FTO analysis required before spending $12K-20K on Patent #2
3. **Firmware completion** — ~30% done. Significant development remains: sensor driver, fusion algorithm, power management, watchdog

### MEDIUM RISKS
1. **No recorded stress test results** — "748 nodes in 22ms" claimed but no test output saved in repo
2. **No database or auth** — production system will need proper infrastructure
3. **PCB design not started** — first custom board, no prior production experience

### LOW RISKS
1. **STM32 availability** — commodity MCU, widely available
2. **Arduino Opta** — small quantity, backup options exist
3. **Market competition** — no direct competitors in distributed ToF bunk monitoring

---

## Go/No-Go Decision Framework

### GO Criteria (All must be met)
- [x] **Architecture configured**: 748-node network defined across 7 buses
- [x] **Partnership confirmed**: Barmount facility access and collaboration
- [ ] **Sensor supply confirmed**: VL53L7CX formal quotes and lead time verified
- [ ] **FTO initiated**: Patent attorney engaged for Schneider analysis
- [ ] **Financial commitment**: Both partners confirm continued investment

### NO-GO Triggers (Any one halts project)
- [ ] VL53L7CX sensors not available in required quantities within acceptable lead time
- [ ] Schneider patent blocks all auto-addressing approaches (assessed after FTO)
- [ ] Budget insufficient for FTO + prototyping combined
- [ ] Partnership terms cannot be agreed

---

## Recommendation

**Current Assessment**: CONDITIONAL GO

### What's strong
- Core technology concept (distributed ToF bunk monitoring) is genuinely novel
- No direct competitor in this space
- Barmount partnership provides real pilot site
- Budget is available for prototyping

### What needs to happen before Week 8 decision
1. **Get VL53L7CX quotes** — formal pricing and lead time from 3+ distributors
2. **Engage patent attorney** — start FTO analysis on Schneider patent
3. **Run and record stress test** — save actual test output to repo
4. **Order sensor samples** — lead time is the bottleneck

### What has changed since v1.0
- Node count aligned to 748 (from codebase, not 540)
- Sensor requirement now 2,992 (was 2,160)
- Prior art threat identified (Schneider auto-addressing patent)
- Predictive Analytics patent dropped (weak case)
- Financial projections revised downward to realistic levels
- Firmware assessed at ~30% complete, not near-complete

---

**Final Decision Point**: March 26, 2026  
**Next Phase (if GO)**: Hardware Prototyping (Week 8-13)  
**Investment Required**: $35,600-76,400 (prototype development)  
**Deliverable**: 50-node pilot system operational at Barmount facility

---

*Go/No-Go Checkpoint Version 2.0*  
*Revised: March 19, 2026*

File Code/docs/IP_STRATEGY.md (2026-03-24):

# BunkScanner IP Strategy & Patent Tracking
## Phase 1 - Intellectual Property Protection

**Status**: PRIOR ART REVIEW COMPLETE — FILING STRATEGY REVISED  
**Revision**: 2.0 — Updated with patent landscape findings (March 2026)  

---

## Prior Art Findings — Critical Issues

### AU2012245501B2 — Schneider Electric (AUTO-ADDRESSING)
**"System and method for automatically addressing devices in a multi-drop network"**  
- Filed: April 2012 | Granted: September 2016 | **ACTIVE**
- Jurisdictions: WO, EP, US, CN, AU, DK
- 25 claims, 41 citations, 64 cited-by

This patent covers automatic address assignment to devices on a shared Modbus/RS-485 bus. Schneider uses random dynamic address + collision detection. BunkScanner uses sequential GPIO daisy-chain (ADDR_IN/ADDR_OUT). The physical mechanism differs, but the functional outcome is identical: automatic address assignment on Modbus RS-485 without manual configuration.

**Impact**: Broad claims in AU2012245501B2 may read onto BunkScanner's approach. **FTO analysis is mandatory before filing Patent #2.**

### US10085419B2 — C-Lock Inc. (FEED MONITORING)
**"Modular livestock feed system for measuring animal intake and monitoring animal behavior"**  
- Filed: July 2016 | Granted: October 2018 | **ACTIVE**

Different approach (individual RFID-gated feed bins vs. open bunk ToF sensors), but the core function of automated feed level/intake monitoring in livestock operations overlaps.

### US7836849B2 — Micro Beef Technologies (BROAD PRIOR ART)
**"Cattle management method and system"**  
- Priority: October 1994 | Granted: November 2010 | Likely expired or expiring

Demonstrates automated feedlot management is not a new concept. 30+ years of prior art. Any broad claims around "automated feedlot monitoring" face prior art challenges.

### US11771057B2 — HerdX, Inc. (LIVESTOCK MANAGEMENT)
- Filed: December 2017 | Granted: October 2023 | **ACTIVE**
- Broad livestock management systems including water monitoring, health analytics
- Risk: LOW-MEDIUM. Different sensor approach.

### CN112653743A — Guangzhou Robustel (RS485 ADDRESSING)
- Filed: December 2020 | Published: April 2021
- Multi-sensor addressing on RS485 bus, sequential within subnets
- Risk: MEDIUM. Chinese patent; may not affect AU/US filing but shows concept is not novel.

---

## Revised Patent Strategy

### 1. Multi-Camera Fill Level Algorithm — PROCEED (Strongest Candidate)
**Technical Basis**: 4× VL53L7CX sensors per node with confidence scoring  
**Innovation**: Per-zone variance analysis + fault detection across 8×8 grid  
**Prior Art Status**: No direct prior art found for ToF multi-sensor feed level with confidence metrics  

**Patent Scope**:
- Multi-sensor feed level determination with confidence metrics
- 8×8 zone grid processing with missing sensor compensation
- Automatic variance-based mixing quality assessment
- Environmental contamination filtering (distance validation)

**Filing Priority**: IMMEDIATE — file after FTO clears  
**Estimated Cost**: $15,000-25,000  
**Recommendation**: Narrow claims to VL53L7CX-specific implementation in agricultural application

### 2. GPIO Daisy-Chain Auto-Addressing — HIGH RISK, DEFER
**Technical Basis**: ADDR_IN/ADDR_OUT sequential propagation  
**Prior Art Threat**: AU2012245501B2 (Schneider)  

**Action Required**:
1. Engage patent attorney for FTO analysis ($10K-15K)
2. Review Schneider's 25 claims against GPIO-specific mechanism
3. Determine if hardware-specific claims are patentable around Schneider's scope
4. File only if FTO is clear — otherwise protect as trade secret

**Filing Priority**: ON HOLD until FTO complete  
**Estimated Cost**: $10K-15K (FTO) + $12K-20K (filing, if cleared)  

### 3. Sensor Fusion Architecture — PROCEED WITH CAUTION
**Technical Basis**: VL53L7CX + backup sensor integration  
**Prior Art Status**: General concept well-known; no ag-specific ToF prior art found  

**Patent Scope**:
- Adaptive sensor fusion for time-of-flight distance measurement in agricultural settings
- Runtime sensor type detection and algorithm switching
- Cross-sensor reliability validation

**Filing Priority**: Week 12-14 (after Patent #1 filed)  
**Estimated Cost**: $10,000-18,000  
**Recommendation**: File narrow claims tied to agricultural ToF application

### 4. Predictive Feed Analytics — DROP FOR NOW
**Technical Basis**: Consumption pattern analysis + anomaly detection  
**Prior Art**: US7836849B2 shows 30 years of automated cattle data analysis  
**Software Patent Weakness**: Software patents are weak in Australia  

**Recommendation**: Save $8K-15K. Focus budget on hardware patents. Revisit if/when unique data patterns emerge from real deployments.

---

## Revised Patent Filing Timeline

| Priority | Patent Application | Cost | Status |
|---|---|---|---|
| **1** | Multi-Camera Algorithm | $15K-25K | Ready to prep — strongest position |
| **2** | FTO Analysis (Schneider patent) | $10K-15K | **MUST DO BEFORE Patent #2 filing** |
| **3** | Auto-Addressing (if FTO clears) | $12K-20K | ON HOLD |
| **4** | Sensor Fusion | $10K-18K | Queue |
| ~~5~~ | ~~Predictive Analytics~~ | ~~$8K-15K~~ | DROPPED — weak case, save budget |

**Revised Total IP Investment**: $47,000-78,000 (includes FTO analysis)  
**If Auto-Addressing blocked**: $35,000-58,000 (patents #1 and #3 only + FTO cost)

---

## Trade Secrets (No Filing — Protect Internally)

- **Modbus protocol extensions**: Custom function codes (FC 0x41-0x43)
- **Calibration algorithms**: Bunk-specific measurements and offsets
- **Manufacturing processes**: PCB assembly and testing procedures
- **Auto-addressing protocol details**: If FTO blocks patent, protect as trade secret instead

## Copyright Protection
- **Source code**: All firmware and software under private ETA license
- **Documentation**: Installation guides, user manuals
- **Web interface**: Dashboard design and visualization

---

## Next Actions (This Week)

1. **Patent attorney**: Interview 3+ firms with ag-tech and IoT experience
2. **FTO analysis**: Priority engagement for AU2012245501B2 review
3. **Patent #1 prep**: Document multi-camera fill level algorithm in detail for filing
4. **Decision**: Auto-addressing — patent vs. trade secret (depends on FTO outcome)

**Critical**: Do not spend $12K-20K filing Patent #2 until the Schneider FTO analysis is complete.

---

*IP Strategy Version 2.0*  
*Revised: March 19, 2026*

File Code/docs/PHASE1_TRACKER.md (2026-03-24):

# BunkScanner Phase 1 Implementation Tracker
## Week 5-7: System Architecture & Design

**Status**: ACTIVE  
**Start Date**: March 19, 2026  
**Phase**: R&D & Technology Development  

---

## Current Milestone: System Architecture Validation

### Tasks in Progress:
- [ ] **Network topology validation**: Confirm 7-bus Modbus architecture scalability
- [ ] **Component supply validation**: VL53L7CX sensor availability (2,160 units)
- [ ] **Market requirements**: Barmount operational requirements confirmation
- [ ] **IP strategy**: Patent search and filing timeline
- [ ] **Manufacturing**: Supplier qualification and pricing validation

### Go/No-Go Checkpoint (Week 8):
**Date**: March 26, 2026  
**Criteria**: Architecture approved + components available  

---

## System Specifications (Validated):

### Hardware Architecture:
- **540 sensor nodes** (STM32G071RBT6)
- **2,160 VL53L7CX sensors** (4 per node)
- **7 Arduino Opta gateways** (Modbus masters)
- **1,295m coverage** across 43 pens (D/C/B sides)

### Network Topology:
- **7 independent RS485 buses** (BUS-D, BUS-C1/C2, BUS-B1/B2, BUS-Z1/Z2)
- **Modbus RTU protocol** at 115200 baud
- **Auto-addressing** via GPIO daisy-chain
- **JSON data aggregation** to central server

### Development Status:
✅ **Backend Server**: Express.js with comprehensive APIs  
✅ **Web Dashboard**: SVG-based real-time visualization  
✅ **Test Framework**: Jest with full coverage  
✅ **Diagnostic Tools**: Bus health and performance monitoring  
🔄 **Firmware**: STM32 and Opta code in development  
🔄 **Hardware**: PCB design and prototyping needed  

---

## Next Actions (This Week):

1. **Architecture Validation** - Confirm current system scales to 540 nodes
2. **Supply Chain** - Validate VL53L7CX availability and pricing  
3. **IP Search** - Patent landscape analysis for filing strategy
4. **Pilot Planning** - Prepare Barmount facility for prototype testing
5. **Manufacturing** - PCB design specs and supplier identification

---

## Investment Tracking:

### Phase 1 Budget: $80,000-150,000 (shared)
**ETA Contribution**: $54,500-103,000 (68%)  
**Barmount Contribution**: $25,500-47,000 (32%)  

**Week 5 Focus**: Architecture & component validation ($5,000-10,000)

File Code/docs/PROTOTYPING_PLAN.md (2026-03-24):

# Hardware Prototyping Plan
## BunkScanner Phase 1 - Weeks 8-13

**Status**: DESIGN PHASE — schematic not yet started  
**Target**: 50-node pilot system for field validation  
**Revision**: 2.0 — March 2026  

---

## STM32G071 Sensor Node PCB Design

### Microcontroller Specifications
- **MCU**: STM32G071RBT6-M0 (QFN-64 package)
- **CPU**: 32-bit ARM Cortex-M0+ at 64 MHz
- **Memory**: 64KB Flash, 36KB SRAM
- **Interfaces**: 2× I2C (400kHz), 1× USART (RS485), GPIO

### Sensor Interface Design
**4× VL53L7CX Time-of-Flight Sensors**
- **Bus 1**: I2C1 — Sensors at 0x54, 0x56 (GPIO enable: PA2, PA3)
- **Bus 2**: I2C2 — Sensors at 0x58, 0x5A (GPIO enable: PA4, PA5)
- **Power Control**: Individual LPn pins per sensor (low-power management)
- **Interrupt Lines**: XSHUT pins connected to GPIO for reset control

**Firmware status for sensor interface**: VL53L7CX driver is ~60% complete. I2C communication partial. Sensor fusion algorithm not yet implemented. Distance-to-fill conversion formula not defined.

### RS485 Communication
- **UART**: USART1 with hardware DE control (PA1)
- **Transceiver**: MAX485 or equivalent (3.3V/5V compatible)
- **Termination**: Switchable 120-ohm resistors via jumper
- **Connector**: RJ45 or terminal block for daisy-chain wiring

### Power System
- **Input**: 24V DC via RS485 cable (shared power/data)
- **Regulation**: 3.3V @ 500mA (linear regulator + switching option)
- **Current Budget**:
  - STM32: ~50mA active, 5uA sleep
  - 4× VL53L7CX: ~100mA measurement, 10uA standby
  - Total: ~150mA active, <20uA sleep

### Auto-Addressing Hardware
- **ADDR_IN**: PA6 input (pulled high, driven low by previous node)
- **ADDR_OUT**: PA7 output (open-drain, pulled high via 10K)
- **Status LED**: PA8 — Node address indication
- **Flash Storage**: Page 63 reserved for address persistence

**Note**: Auto-addressing firmware is written but untested on physical hardware. Prior art concern with AU2012245501B2 (Schneider) — see IP_STRATEGY.md.

---

## PCB Design Specifications

### Board Size & Layout
- **Form Factor**: 60mm × 40mm (fits standard enclosure)
- **Layers**: 4-layer PCB (power/ground planes)
- **Mounting**: 4× M3 holes for bracket attachment
- **Environmental**: Conformal coating for feedlot conditions

### Component Placement
```
    [VL53L7CX-1] [VL53L7CX-2]
         |            |
    [VL53L7CX-3] [VL53L7CX-4]
         |            |
    +--[STM32G071]----[MAX485]--+
    |                           |
    [Power Reg]----[24V Input]--+
    |                           |
    +--[ADDR I/O]----[Status]---+
```

### Connector Design
- **Power/RS485**: RJ45 or 6-pin terminal (24V, GND, A+, B-, ADDR_IN, ADDR_OUT)
- **Programming**: 10-pin SWD header (production programming)
- **Test Points**: I2C buses, power rails, control signals

---

## Prototyping Timeline

### Week 8-9: PCB Design
- [ ] **Schematic Design**: Complete electrical design and component selection
- [ ] **PCB Layout**: 4-layer routing with proper power distribution
- [ ] **Design Review**: Internal validation + external consultant review
- [ ] **Fabrication Files**: Gerber generation and manufacturer selection

### Week 10-11: PCB Fabrication & Assembly
- [ ] **Fabrication**: PCB manufacturing (5-7 day lead time)
- [ ] **Component Procurement**: Order all components for 50 prototypes
- [ ] **Assembly**: Hand assembly or prototype assembly service
- [ ] **Initial Testing**: Power-on, programming, basic functionality

### Week 12-13: System Integration
- [ ] **Firmware Integration**: Load production firmware on prototypes
- [ ] **Sensor Calibration**: VL53L7CX initialization and testing
- [ ] **Communication Testing**: RS485 and auto-addressing validation on hardware
- [ ] **Environmental Testing**: Temperature, humidity, vibration tests

**Prerequisite**: VL53L7CX sensor samples must be ordered by Week 6 to arrive in time. 8-16 week lead time is the bottleneck.

---

## 50-Node Pilot Test Plan

### Configuration
**Setup**: Single bus (BUS-D equivalent)  
**Coverage**: 12-15 pens at Barmount facility  
**Duration**: 2-week continuous operation test  

### Test Scenarios
1. **Auto-Addressing**: 50 nodes in daisy-chain configuration
2. **Data Collection**: 30-second polling cycle, data integrity validation
3. **Environmental**: Outdoor installation, weather resistance testing
4. **Reliability**: 24/7 operation with failure rate monitoring
5. **Accuracy**: Feed level measurements vs. manual bunk scoring

### Success Criteria
- [ ] **100% Auto-Addressing**: All 50 nodes automatically configured
- [ ] **>99% Uptime**: Less than 1% communication failures
- [ ] **+-5cm Accuracy**: Feed level measurement within specification
- [ ] **14-Day Reliability**: Continuous operation without intervention

### What Must Be Done Before Pilot
- [ ] VL53L7CX driver completed (currently ~60%)
- [ ] Sensor fusion / confidence scoring implemented
- [ ] Distance-to-fill conversion formula defined and calibrated
- [ ] Power management firmware completed
- [ ] Watchdog / recovery firmware implemented

---

## Manufacturing Scaling (Post-Pilot)

### Full Deployment: 748 Nodes
- **748× STM32G071RBT6**: $1,496-2,992
- **2,992× VL53L7CX**: $17,952-29,920 (bulk pricing)
- **748× Custom PCBs**: $11,220-18,700 (design + assembly)
- **Enclosures & Hardware**: $3,740-11,220

### Manufacturing Partners
- [ ] Qualify 2-3 PCB fabrication shops
- [ ] SMT assembly service for volume production
- [ ] Automated testing and programming setup
- [ ] Quality control and batch testing procedures

### Production Timeline (Per Batch)
- PCB Fabrication: 7-10 days
- Component Assembly: 5-7 days (automated SMT)
- Testing & Programming: 2-3 days (batch)
- Total: 14-20 days for 748 nodes

---

## Budget (Corrected)

### Prototyping Costs (50-Node Pilot)
| Item | Cost |
|---|---|
| PCB Design & Layout | $8,000-12,000 |
| 50× Prototype PCBs | $2,500-5,000 |
| 200× VL53L7CX sensors (pilot + spares) | $1,600-2,400 |
| 50× STM32G071 + passives | $500-1,000 |
| Assembly & Testing | $3,000-8,000 |
| Design Tools & Equipment | $2,000-5,000 |
| **Prototype Total** | **$17,600-33,400** |

### Production Preparation
| Item | Cost |
|---|---|
| Manufacturing tooling | $5,000-10,000 |
| Quality systems setup | $3,000-8,000 |
| Volume component deposits | $10,000-25,000 |
| **Production Prep Total** | **$18,000-43,000** |

**Combined Phase 1 Hardware**: $35,600-76,400

---

## Next Actions

1. **Order VL53L7CX samples** — lead time is 8-16 weeks, start now
2. **Begin schematic in KiCad** — STM32G071 + VL53L7CX circuit design
3. **Complete firmware gaps** — VL53L7CX driver, sensor fusion, power management
4. **Identify PCB fab partners** — get quotes for 50-board pilot run
5. **Acquire test equipment** — oscilloscope, logic analyser, power supplies

**Critical path**: Sensor availability determines when prototyping can begin.

---

*Prototyping Plan Version 2.0*  
*Revised: March 19, 2026*

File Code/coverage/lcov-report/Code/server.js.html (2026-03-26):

# All files / Code server.js

78.68% Statements 48/61

75% Branches 9/12

83.33% Functions 5/6

78.68% Lines 48/61

Press n or j to go to the next uncovered block, b, p or k for the previous block.

1
2
3
4
5
6
7
8
9
10
11
12
13
14
15
16
17
18
19
20
21
22
23
24
25
26
27
28
29
30
31
32
33
34
35
36
37
38
39
40
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

1x
1x

1x

1x

1x
1x

1x
1x
1x
1x

1x

1x

1x

1x
50x

50x
50x

8x
8x

42x

42x

42x
42x

1x

7x

7x
7x
7x

7x

1x
4x
4x

4x
2x

4x

4x

1x
9x

9x
1x

8x
8x

1x

1x
2x

1x

1x

1x

/**
* BunkScanner Backend Server
*
* Lightweight Node.js/Express server that:
* 1. Receives POST /api/bus/data from Opta gateways (RS485 bus data)
* 2. Aggregates data from all 7 buses into a unified site view
* 3. Serves GET /api/site to the web dashboard
* 4. Serves the static web frontend
*
* Run: node Code/server.js
* Requires: npm install express
*/

const express = require('express');
const path = require('path');
const {
logger,
validateBusPayload,
BusHealthMonitor,
requestLogger,
jsonParseErrorHandler,
globalErrorHandler,
apiNotFoundHandler,
setupProcessHandlers,
VALID_BUSES,
} = require('./lib/errorHandler');

const app = express();

const PORT = process.env.PORT || 3000;
const MAX_BODY_SIZE = '1mb';

/* ══════════════════════════════════════════════════════
MIDDLEWARE
══════════════════════════════════════════════════════ */

app.use(requestLogger);
app.use(express.json({ limit: MAX_BODY_SIZE }));
app.use(jsonParseErrorHandler);
app.use(express.static(path.join(__dirname, 'web')));

const healthMonitor = new BusHealthMonitor();

/* ══════════════════════════════════════════════════════
IN-MEMORY DATA STORE
══════════════════════════════════════════════════════ */

// Stores latest data from each bus, keyed by busId
const busData = {};

// Bus health tracking
const busHealth = {};

/* ══════════════════════════════════════════════════════
API: Receive bus data from Opta gateways
POST /api/bus/data
══════════════════════════════════════════════════════ */

app.post('/api/bus/data', (req, res) => {
const payload = req.body;

try {
validateBusPayload(payload);
} catch (err) {
logger.warn('BUS', `Invalid payload from ${req.ip}: ${err.message}`);
return res.status(err.statusCode || 400).json(err.toJSON ? err.toJSON() : { error: err.message });
}

// Store with server timestamp
busData[payload.busId] = {
...payload,
receivedAt: Date.now(),
};

// Update health
busHealth[payload.busId] = {
lastSeen: Date.now(),
nodeCount: payload.nodeCount || payload.nodes.length,
online: true,
};

logger.info('BUS', `${payload.busId}: ${payload.nodes.length} nodes received`);
res.json({ status: 'ok', busId: payload.busId });
});

/* ══════════════════════════════════════════════════════
API: Get aggregated site data for web dashboard
GET /api/site
══════════════════════════════════════════════════════ */

app.get('/api/site', (_req, res) => {
// Return all bus data for the frontend to merge into its data model
const buses = Object.values(busData);

// Mark stale buses (no data for >60s)
const now = Date.now();
for (const bus of buses) {
bus.stale = (now - bus.receivedAt) > 60000;
}

res.json({
timestamp: now,
buses: buses,
health: busHealth,
});
});

/* ══════════════════════════════════════════════════════
API: Get bus health summary
GET /api/health
══════════════════════════════════════════════════════ */

app.get('/api/health', (_req, res) => {
const now = Date.now();
const summary = {};

for (const [busId, health] of Object.entries(busHealth)) {
summary[busId] = {
...health,
stale: (now - health.lastSeen) > 60000,
lastSeenAgo: Math.round((now - health.lastSeen) / 1000) + 's',
};
}

// Include health monitor diagnostics
const diagnostics = healthMonitor.getHealthStatus(busHealth);

res.json({
timestamp: now,
totalBuses: Object.keys(summary).length,
expectedBuses: 7,
buses: summary,
diagnostics,
});
});

/* ══════════════════════════════════════════════════════
API: Trigger re-addressing on a specific bus
POST /api/bus/:busId/readdress
══════════════════════════════════════════════════════ */

app.post('/api/bus/:busId/readdress', (req, res) => {
const { busId } = req.params;

if (!VALID_BUSES.includes(busId)) {
return res.status(400).json({ error: { code: 'INVALID_BUS', message: `Unknown busId: ${busId}` } });
}

// In production, this would send a command to the Opta gateway
// For now, just clear the bus data to force a refresh
logger.info('CMD', `Re-address requested for ${busId}`);
res.json({ status: 'queued', busId: busId });
});

/* ══════════════════════════════════════════════════════
STATIC FALLBACK — Serve index.html for SPA routes
══════════════════════════════════════════════════════ */

app.use(apiNotFoundHandler);

app.get('*', (_req, res) => {
res.sendFile(path.join(__dirname, 'web', 'index.html'));
});

/* ══════════════════════════════════════════════════════
GLOBAL ERROR HANDLER (must be last middleware)
══════════════════════════════════════════════════════ */

app.use(globalErrorHandler);

/* ══════════════════════════════════════════════════════
START SERVER (only when run directly)
══════════════════════════════════════════════════════ */

Iif (require.main === module) {
setupProcessHandlers();

app.listen(PORT, () => {
logger.info('SERVER', 'BunkScanner Server started', { port: PORT });
console.log('==============================');
console.log('BunkScanner Server');
console.log(`Listening on port ${PORT}`);
console.log('==============================');
console.log('Endpoints:');
console.log(` POST /api/bus/data — Receive Opta gateway data`);
console.log(` GET /api/site — Aggregated site data for dashboard`);
console.log(` GET /api/health — Bus health summary`);
console.log(` POST /api/bus/:id/readdress — Trigger re-addressing`);
console.log('==============================');
});
}

/* ══════════════════════════════════════════════════════
EXPORTS (for testing)
══════════════════════════════════════════════════════ */

module.exports = { app, busData, busHealth, healthMonitor };

Code coverage generated by istanbul (https://istanbul.js.org/) at 2026-03-26T01:10:01.539Z

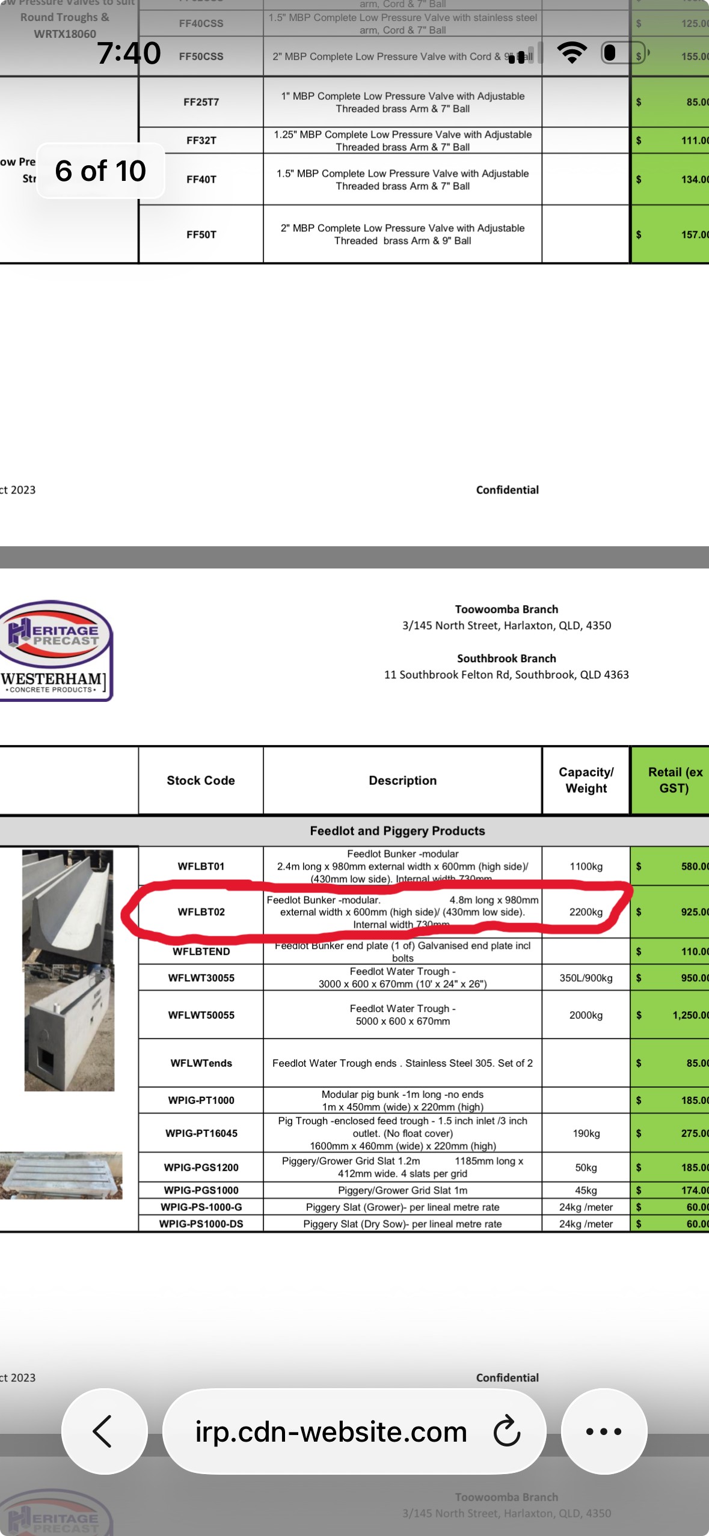
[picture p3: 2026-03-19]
Research/BUNK BRAND AND PROFILE.jpg

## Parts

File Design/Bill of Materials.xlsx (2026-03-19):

ID | Description | Manufacturer | Supplier | QTY | Cost | Total
VL53L7CX | Time-of-Flight 8x8 multizone ranging sensor with 90 degrees FoV | ST electronics (https://www.st.com/en/embedded-software/stsw-img036.html)
VL53L7CX-breakout | breakout board for prototype | Pololu (https://www.pololu.com/product-info-merged/3418) | Digikey (https://www.digikey.com.au/en/products/detail/pololu/3418/21283765) |  | $19.95

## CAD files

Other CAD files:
Design/3D/00 INSTALLATION.iam
Design/3D/Bunk 1.ipt
Design/3D/OldVersions/00 INSTALLATION.0001.iam
Design/3D/OldVersions/vl53l7cx-FOV.0001.ipt
Design/3D/OldVersions/vl53l7cx-carrier-model-FOV.0003.ipt
Design/3D/OldVersions/vl53l7cx-carrier-model.0001.iam
Design/3D/OldVersions/vl53l7cx-carrier-model.0001.ipt
Design/3D/vl53l7cx-FOV.ipt
Design/3D/vl53l7cx-carrier-model-FOV.ipt
Design/3D/vl53l7cx-carrier-model.iam
Design/3D/vl53l7cx-carrier-model.ipt

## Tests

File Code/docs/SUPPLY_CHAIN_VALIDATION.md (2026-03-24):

# Component Supply Chain Validation
## BunkScanner Phase 1

**Status**: VALIDATION IN PROGRESS — pricing updated with real-world data  
**Critical Path**: VL53L7CX sensor availability (single-source risk)  
**Revision**: 2.0 — March 2026  

---

## Critical Components Analysis

### VL53L7CX Time-of-Flight Sensors — HIGH RISK
**Requirement**: 2,992 units (4 per node × 748 nodes)  
**Manufacturer**: STMicroelectronics (sole source — no pin-compatible alternative exists)  

| Source | Qty 1 Price | Bulk (2,000+) | Lead Time |
|---|---|---|---|
| DigiKey | ~$10-12 USD | ~$8-10 | 8-16 weeks |
| Mouser | ~$10-12 USD | ~$8-10 | 8-16 weeks |
| ST Direct | Quote required | Est. $6-10 | 8-16 weeks |

**Estimated Total Cost**: $17,952-29,920 (at $6-10 bulk) — lower than previous estimate of $25,920-38,880

**Risk Factors**:
- **Single source**: ST Microelectronics is the only manufacturer. No alternative exists
- **TI OPT3101 is NOT a backup**: Different sensor type (active IR, not multi-zone ToF), different I2C interface, different data format. Requires complete firmware rewrite — not a drop-in replacement
- **Chip shortage volatility**: Semiconductor availability still fluctuates
- **Lead time**: 8-16 weeks means ordering must happen early in prototyping phase

**Mitigation**:
- Get formal quotes from 3+ distributors immediately
- Consider ordering pilot batch (200 units) now to secure supply
- Investigate ST's allocation/priority customer programs
- Accept single-source risk for now — no viable alternative for 8×8 multi-zone ToF

### STM32G071RBT6 Microcontrollers — LOW RISK
**Requirement**: 748 units (1 per sensor node)  
**Manufacturer**: STMicroelectronics  

| Source | Qty 1 Price | Bulk (500+) |
|---|---|---|
| Various distributors | $3-5 | $2-4 |

**Estimated Total Cost**: $1,496-2,992  
**Availability**: Widely stocked at multiple distributors  
**Package**: QFN-64 — standard, well-supported  
**Risk**: LOW. Multiple distributors, reasonable pricing, high availability.

### Arduino Opta Gateways — LOW-MEDIUM RISK
**Requirement**: 7 units (1 per bus)  
**Supplier**: Arduino (official)  

| Source | Price | Volume |
|---|---|---|
| Arduino official | $150-180 | 7 units (trivial) |
| Alt: RPi + RS485 HAT | $80-120 | Viable backup |

**Estimated Total Cost**: $1,050-1,260  
**Risk**: LOW. Small quantity, multiple sourcing options.

---

## Supply Chain Risk Matrix

| Component | Qty | Single Source? | Risk | Mitigation |
|---|-----|---|---|---|
| **VL53L7CX** | 2,992 | YES | **HIGH** | Order early, secure allocation |
| **STM32G071** | 748 | No (multiple distributors) | LOW | Standard procurement |
| **Arduino Opta** | 7 | No (RPi backup) | LOW | Trivial volume |
| **MAX485 transceiver** | 748 | No | LOW | Commodity part |
| **PCB fabrication** | 748+ | No (multiple fabs) | LOW | Standard 4-layer process |
| **Passive components** | Various | No | LOW | Commodity |
| **Connectors** | Various | No | LOW | Standard RJ45/terminal |

---

## Budget Summary (Corrected)

### Component Costs (Full 748-Node Deployment)
| Component | Quantity | Unit Cost | Total |
|---|---|---|---|
| VL53L7CX sensors | 2,992 | $6-10 | $17,952-29,920 |
| STM32G071 MCUs | 748 | $2-4 | $1,496-2,992 |
| Arduino Opta | 7 | $150-180 | $1,050-1,260 |
| Custom PCBs | 748 | $15-25 | $11,220-18,700 |
| Passives + connectors | Various | — | $3,000-6,000 |
| Enclosures + mounting | 748 | $5-15 | $3,740-11,220 |
| **Total** | | | **$38,458-70,092** |

### Phase 1 Procurement (50-Node Pilot)
| Item | Cost |
|---|---|
| Sensor samples (200 VL53L7CX) | $1,600-2,400 |
| MCU samples (50 STM32G071) | $150-250 |
| Prototype PCBs (50 boards) | $2,500-5,000 |
| Passives + connectors | $500-1,000 |
| **Pilot total** | **$4,750-8,650** |

---

## Next Actions

1. **Get formal VL53L7CX quotes** from ST direct, DigiKey, Mouser, Arrow — confirm lead time and bulk pricing for 200-unit pilot batch and 3,000-unit production
2. **Order pilot sensors** (200 units) as soon as pricing confirmed — lead time is the bottleneck
3. **Confirm STM32G071 availability** at distributors for 50-unit pilot
4. **PCB fabrication quotes** — identify 2-3 manufacturers for 4-layer prototype boards
5. **Drop TI OPT3101 as "backup"** — it is not a viable alternative. Accept single-source risk and focus on securing ST supply

---

*Supply Chain Validation Version 2.0*  
*Revised: March 19, 2026*

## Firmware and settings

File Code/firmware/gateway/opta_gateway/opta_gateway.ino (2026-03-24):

/**
 * BunkScanner Gateway — Arduino Opta
 *
 * RS485 bus master that:
 * 1. Runs daisy-chain auto-addressing on boot
 * 2. Polls all addressed nodes via Modbus RTU (registers 0–7)
 * 3. Pushes aggregated JSON data to web server via Ethernet
 * 4. Reports bus health and handles re-addressing
 *
 * Hardware: Arduino Opta (built-in RS485 + Ethernet)
 * Protocol: Modbus RTU at 115200 baud
 */

#include <ArduinoRS485.h>
#include <Ethernet.h>
#include <ArduinoJson.h>

/* ════════════════════════════════════════════════════════════
   CONFIGURATION — Edit per gateway
   ════════════════════════════════════════════════════════════ */

// Bus identity — set uniquely per Opta unit
const char* BUS_ID    = "BUS-D";   // BUS-D, BUS-C1, BUS-C2, BUS-B1, BUS-B2, BUS-Z1, BUS-Z2
const char* SIDE      = "D";       // D, C, C, B, B, Z, Z
const int   PEN_START = 1;         // First pen number on this bus
const int   PEN_END   = 8;         // Last pen number on this bus

// Network
byte mac[] = { 0xDE, 0xAD, 0xBE, 0xEF, 0x00, 0x01 }; // Unique per Opta
IPAddress serverIP(192, 168, 1, 100);
const int  serverPort = 3000;
const char* apiPath   = "/api/bus/data";

// Timing
const unsigned long POLL_INTERVAL_MS       = 5000;   // Poll all nodes every 5s
const unsigned long MODBUS_TIMEOUT_MS      = 50;     // Response timeout per node
const unsigned long MODBUS_INTER_FRAME_MS  = 5;      // Silence between frames
const unsigned long ADDRESSING_TIMEOUT_MS  = 100;    // Wait for address ACK
const unsigned long HEALTH_REPORT_MS       = 30000;  // Report bus health every 30s
const int           MAX_CONSECUTIVE_FAILS  = 5;      // Trigger re-address after N failures

/* ════════════════════════════════════════════════════════════
   MODBUS PROTOCOL CONSTANTS
   ════════════════════════════════════════════════════════════ */

#define MODBUS_FC_READ_HOLDING   0x03
#define MODBUS_FC_ASSIGN_ADDR    0x41
#define MODBUS_FC_ADDR_COMPLETE  0x42
#define MODBUS_FC_FULL_DATA      0x43

#define MAX_NODES                128
#define REGS_PER_NODE            8

// Register indices
#define REG_STATUS      0
#define REG_CAM1_FILL   1
#define REG_CAM2_FILL   2
#define REG_CAM3_FILL   3
#define REG_CAM4_FILL   4
#define REG_AVG_FILL    5
#define REG_VARIANCE    6
#define REG_CONFIDENCE  7

/* ════════════════════════════════════════════════════════════
   NODE DATA STRUCTURE
   ════════════════════════════════════════════════════════════ */

struct NodeData {
    uint8_t  address;
    uint16_t registers[REGS_PER_NODE];
    bool     online;
    uint8_t  failCount;
    unsigned long lastSeen;
};

NodeData nodes[MAX_NODES];
int nodeCount = 0;
bool addressingDone = false;

// CRC buffer
uint8_t txBuf[32];
uint8_t rxBuf[64];

// Ethernet client
EthernetClient client;

// Timing
unsigned long lastPoll = 0;
unsigned long lastHealthReport = 0;

/* ════════════════════════════════════════════════════════════
   CRC-16/MODBUS
   ════════════════════════════════════════════════════════════ */

uint16_t modbusCRC16(const uint8_t* data, uint16_t len) {
    uint16_t crc = 0xFFFF;
    for (uint16_t i = 0; i < len; i++) {
        crc ^= data[i];
        for (uint8_t j = 0; j < 8; j++) {
            if (crc & 1)
                crc = (crc >> 1) ^ 0xA001;
            else
                crc >>= 1;
        }
    }
    return crc;
}

/* ════════════════════════════════════════════════════════════
   RS485 RAW SEND/RECEIVE
   ════════════════════════════════════════════════════════════ */

void rs485Send(const uint8_t* data, int len) {
    RS485.beginTransmission();
    RS485.write(data, len);
    RS485.endTransmission();
}

int rs485Receive(uint8_t* buf, int maxLen, unsigned long timeoutMs) {
    unsigned long start = millis();
    int idx = 0;
    unsigned long lastByte = 0;

    while (millis() - start < timeoutMs) {
        if (RS485.available()) {
            if (idx < maxLen) {
                buf[idx++] = RS485.read();
                lastByte = millis();
            }
        } else if (idx > 0 && millis() - lastByte > MODBUS_INTER_FRAME_MS) {
            break; // Inter-frame silence detected
        }
    }
    return idx;
}

/* ════════════════════════════════════════════════════════════
   MODBUS MASTER — READ HOLDING REGISTERS
   ════════════════════════════════════════════════════════════ */

bool modbusReadHolding(uint8_t addr, uint16_t startReg, uint16_t numRegs,
                        uint16_t* outRegs) {
    // Build request: [addr, FC, startHi, startLo, numHi, numLo, CRClo, CRChi]
    txBuf[0] = addr;
    txBuf[1] = MODBUS_FC_READ_HOLDING;
    txBuf[2] = (startReg >> 8) & 0xFF;
    txBuf[3] = startReg & 0xFF;
    txBuf[4] = (numRegs >> 8) & 0xFF;
    txBuf[5] = numRegs & 0xFF;
    uint16_t crc = modbusCRC16(txBuf, 6);
    txBuf[6] = crc & 0xFF;
    txBuf[7] = (crc >> 8) & 0xFF;

    rs485Send(txBuf, 8);
    delay(MODBUS_INTER_FRAME_MS);

    int rxLen = rs485Receive(rxBuf, sizeof(rxBuf), MODBUS_TIMEOUT_MS);

    // Validate response
    if (rxLen < 5) return false;

    // Check CRC
    uint16_t rxCRC = rxBuf[rxLen - 2] | (rxBuf[rxLen - 1] << 8);
    if (rxCRC != modbusCRC16(rxBuf, rxLen - 2)) return false;

    // Check address and function code
    if (rxBuf[0] != addr || rxBuf[1] != MODBUS_FC_READ_HOLDING) return false;

    // Extract register values
    uint8_t byteCount = rxBuf[2];
    if (byteCount != numRegs * 2) return false;

    for (uint16_t i = 0; i < numRegs; i++) {
        outRegs[i] = (rxBuf[3 + i * 2] << 8) | rxBuf[3 + i * 2 + 1];
    }

    return true;
}

/* ════════════════════════════════════════════════════════════
   AUTO-ADDRESSING — DAISY CHAIN ORCHESTRATION
   ════════════════════════════════════════════════════════════ */

int runAutoAddressing() {
    Serial.println("[ADDR] Starting auto-addressing sequence...");
    nodeCount = 0;

    for (int addr = 1; addr <= MAX_NODES; addr++) {
        // Build ASSIGN_ADDRESS broadcast: [0x00, 0x41, addr, CRClo, CRChi]
        txBuf[0] = 0x00;  // Broadcast
        txBuf[1] = MODBUS_FC_ASSIGN_ADDR;
        txBuf[2] = (uint8_t)addr;
        uint16_t crc = modbusCRC16(txBuf, 3);
        txBuf[3] = crc & 0xFF;
        txBuf[4] = (crc >> 8) & 0xFF;

        rs485Send(txBuf, 5);
        delay(MODBUS_INTER_FRAME_MS);

        // Wait for ACK: [addr, 0x41, addr, CRClo, CRChi]
        int rxLen = rs485Receive(rxBuf, sizeof(rxBuf), ADDRESSING_TIMEOUT_MS);

        if (rxLen < 5) {
            Serial.print("[ADDR] No response at address ");
            Serial.print(addr);
            Serial.println(" — end of chain.");
            break;
        }

        // Validate ACK
        uint16_t rxCRC = rxBuf[rxLen - 2] | (rxBuf[rxLen - 1] << 8);
        if (rxCRC != modbusCRC16(rxBuf, rxLen - 2) ||
            rxBuf[0] != addr || rxBuf[1] != MODBUS_FC_ASSIGN_ADDR ||
            rxBuf[2] != addr) {
            Serial.print("[ADDR] Invalid ACK at address ");
            Serial.println(addr);
            break;
        }

        // Node accepted address
        nodes[nodeCount].address = addr;
        nodes[nodeCount].online = true;
        nodes[nodeCount].failCount = 0;
        nodes[nodeCount].lastSeen = millis();
        memset(nodes[nodeCount].registers, 0, sizeof(nodes[nodeCount].registers));
        nodeCount++;

        Serial.print("[ADDR] Node ");
        Serial.print(addr);
        Serial.println(" addressed OK");

        delay(10); // Small delay for daisy chain propagation
    }

    // Send ADDR_COMPLETE broadcast
    txBuf[0] = 0x00;
    txBuf[1] = MODBUS_FC_ADDR_COMPLETE;
    uint16_t crc = modbusCRC16(txBuf, 2);
    txBuf[2] = crc & 0xFF;
    txBuf[3] = (crc >> 8) & 0xFF;
    rs485Send(txBuf, 4);

    addressingDone = (nodeCount > 0);

    Serial.print("[ADDR] Complete: ");
    Serial.print(nodeCount);
    Serial.println(" nodes addressed.");

    return nodeCount;
}

/* ════════════════════════════════════════════════════════════
   POLL ALL NODES
   ════════════════════════════════════════════════════════════ */

void pollAllNodes() {
    int onlineCount = 0;
    int faultCount = 0;

    for (int i = 0; i < nodeCount; i++) {
        uint16_t regs[REGS_PER_NODE];
        bool ok = modbusReadHolding(nodes[i].address, 0, REGS_PER_NODE, regs);

        if (ok) {
            memcpy(nodes[i].registers, regs, sizeof(regs));
            nodes[i].online = true;
            nodes[i].failCount = 0;
            nodes[i].lastSeen = millis();
            onlineCount++;
        } else {
            nodes[i].failCount++;
            if (nodes[i].failCount >= MAX_CONSECUTIVE_FAILS) {
                nodes[i].online = false;
                faultCount++;
            }
        }

        delay(MODBUS_INTER_FRAME_MS);
    }

    // If too many nodes went offline, trigger re-addressing
    if (faultCount > nodeCount / 3 && nodeCount > 0) {
        Serial.println("[BUS] Too many faults — triggering re-addressing");
        runAutoAddressing();
    }
}

/* ════════════════════════════════════════════════════════════
   JSON DATA BUILDER
   ════════════════════════════════════════════════════════════ */

String buildBusDataJSON() {
    // Calculate buffer size: ~100 bytes per node + overhead
    const size_t capacity = JSON_OBJECT_SIZE(4) +
                            JSON_ARRAY_SIZE(nodeCount) +
                            nodeCount * JSON_OBJECT_SIZE(10);
    DynamicJsonDocument doc(capacity > 16384 ? capacity : 16384);

    doc["busId"] = BUS_ID;
    doc["side"] = SIDE;
    doc["timestamp"] = millis();
    doc["nodeCount"] = nodeCount;

    JsonArray nodesArr = doc.createNestedArray("nodes");

    // Map Modbus address → pen/segment based on position
    int segmentIndex = 0;
    int currentPen = PEN_START;
    int segInPen = 1;

    for (int i = 0; i < nodeCount; i++) {
        if (!nodes[i].online) {
            segmentIndex++;
            segInPen++;
            continue;
        }

        JsonObject n = nodesArr.createNestedObject();
        n["addr"] = nodes[i].address;

        // Build node ID: e.g. "D01-S05"
        char nodeId[12];
        snprintf(nodeId, sizeof(nodeId), "%s%02d-S%02d", SIDE, currentPen, segInPen);
        n["id"] = nodeId;

        n["status"]     = nodes[i].registers[REG_STATUS];
        n["cam1Fill"]   = nodes[i].registers[REG_CAM1_FILL];
        n["cam2Fill"]   = nodes[i].registers[REG_CAM2_FILL];
        n["cam3Fill"]   = nodes[i].registers[REG_CAM3_FILL];
        n["cam4Fill"]   = nodes[i].registers[REG_CAM4_FILL];
        n["avgFill"]    = nodes[i].registers[REG_AVG_FILL];
        n["variance"]   = nodes[i].registers[REG_VARIANCE];
        n["confidence"] = nodes[i].registers[REG_CONFIDENCE];

        segmentIndex++;
        segInPen++;

        /* Pen boundary detection:
         * This is approximate — the exact segment count per pen is
         * configured in the bus mapping table. For now, use the known
         * segments-per-pen from the LAYOUT configuration. The server
         * holds the authoritative pen→segment mapping. */
    }

    String output;
    serializeJson(doc, output);
    return output;
}

/* ════════════════════════════════════════════════════════════
   ETHERNET — POST DATA TO SERVER
   ════════════════════════════════════════════════════════════ */

bool postDataToServer(const String& jsonData) {
    if (client.connect(serverIP, serverPort)) {
        client.print("POST ");
        client.print(apiPath);
        client.println(" HTTP/1.1");
        client.print("Host: ");
        client.print(serverIP);
        client.print(":");
        client.println(serverPort);
        client.println("Content-Type: application/json");
        client.print("Content-Length: ");
        client.println(jsonData.length());
        client.println("Connection: close");
        client.println();
        client.print(jsonData);

        // Read response (non-blocking, just drain)
        unsigned long start = millis();
        while (client.connected() && millis() - start < 2000) {
            while (client.available()) {
                client.read(); // Drain response
            }
        }
        client.stop();
        return true;
    }

    Serial.println("[ETH] Connection to server failed");
    return false;
}

/* ════════════════════════════════════════════════════════════
   BUS HEALTH REPORT
   ════════════════════════════════════════════════════════════ */

void reportBusHealth() {
    int online = 0;
    int offline = 0;
    for (int i = 0; i < nodeCount; i++) {
        if (nodes[i].online) online++;
        else offline++;
    }

    Serial.print("[HEALTH] Bus ");
    Serial.print(BUS_ID);
    Serial.print(": ");
    Serial.print(online);
    Serial.print(" online, ");
    Serial.print(offline);
    Serial.print(" offline, ");
    Serial.print(nodeCount);
    Serial.println(" total");
}

/* ════════════════════════════════════════════════════════════
   SETUP & LOOP
   ════════════════════════════════════════════════════════════ */

void setup() {
    Serial.begin(115200);
    while (!Serial && millis() < 3000); // Wait for serial (max 3s)

    Serial.println("==============================");
    Serial.print("BunkScanner Gateway — ");
    Serial.println(BUS_ID);
    Serial.println("==============================");

    // Initialize RS485 at 115200 baud
    RS485.begin(115200);
    RS485.receive();
    Serial.println("[RS485] Initialized at 115200 baud");

    // Initialize Ethernet
    Serial.println("[ETH] Initializing...");
    if (Ethernet.begin(mac) == 0) {
        Serial.println("[ETH] DHCP failed, using fallback IP");
        IPAddress fallbackIP(192, 168, 1, 200);
        Ethernet.begin(mac, fallbackIP);
    }
    Serial.print("[ETH] IP: ");
    Serial.println(Ethernet.localIP());

    // Run auto-addressing
    delay(2000); // Wait for all nodes to boot
    runAutoAddressing();

    // Post initial bus mapping to server
    if (addressingDone) {
        String json = buildBusDataJSON();
        postDataToServer(json);
    }

    lastPoll = millis();
    lastHealthReport = millis();
}

void loop() {
    unsigned long now = millis();

    // Poll all nodes at interval
    if (now - lastPoll >= POLL_INTERVAL_MS && addressingDone) {
        lastPoll = now;
        pollAllNodes();

        // Build and send data
        String json = buildBusDataJSON();
        postDataToServer(json);
    }

    // Periodic health report to serial
    if (now - lastHealthReport >= HEALTH_REPORT_MS) {
        lastHealthReport = now;
        reportBusHealth();
    }

    // Maintain Ethernet
    Ethernet.maintain();
}

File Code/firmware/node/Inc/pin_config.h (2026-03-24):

/**
 * BunkScanner Node — Pin Configuration
 * Target: STM32G071RBT6 (LQFP48)
 */
#ifndef PIN_CONFIG_H
#define PIN_CONFIG_H

#include "stm32g0xx_hal.h"

/* ── I2C1: CAM1 + CAM2 (left half of segment) ── */
#define I2C1_SCL_PORT       GPIOB
#define I2C1_SCL_PIN        GPIO_PIN_6
#define I2C1_SDA_PORT       GPIOB
#define I2C1_SDA_PIN        GPIO_PIN_7
#define I2C1_AF             GPIO_AF6_I2C1

/* ── I2C2: CAM3 + CAM4 (right half of segment) ── */
#define I2C2_SCL_PORT       GPIOA
#define I2C2_SCL_PIN        GPIO_PIN_11
#define I2C2_SDA_PORT       GPIOA
#define I2C2_SDA_PIN        GPIO_PIN_12
#define I2C2_AF             GPIO_AF6_I2C2

/* ── USART2: RS485 with hardware DE ── */
#define RS485_TX_PORT       GPIOA
#define RS485_TX_PIN        GPIO_PIN_2
#define RS485_RX_PORT       GPIOA
#define RS485_RX_PIN        GPIO_PIN_3
#define RS485_DE_PORT       GPIOA
#define RS485_DE_PIN        GPIO_PIN_1
#define RS485_AF            GPIO_AF1_USART2
#define RS485_BAUDRATE      115200

/* ── VL53L7CX LPn (enable) pins ── */
#define CAM1_LPN_PORT       GPIOB
#define CAM1_LPN_PIN        GPIO_PIN_0
#define CAM2_LPN_PORT       GPIOB
#define CAM2_LPN_PIN        GPIO_PIN_1
#define CAM3_LPN_PORT       GPIOB
#define CAM3_LPN_PIN        GPIO_PIN_2
#define CAM4_LPN_PORT       GPIOB
#define CAM4_LPN_PIN        GPIO_PIN_3

/* ── Auto-addressing daisy chain ── */
#define ADDR_IN_PORT        GPIOA
#define ADDR_IN_PIN         GPIO_PIN_0      /* Input, pulled high by next node */
#define ADDR_OUT_PORT       GPIOA
#define ADDR_OUT_PIN        GPIO_PIN_4      /* Open-drain output */

/* ── Status LED ── */
#define LED_PORT            GPIOC
#define LED_PIN             GPIO_PIN_6

#endif /* PIN_CONFIG_H */

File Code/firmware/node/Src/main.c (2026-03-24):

/**
 * BunkScanner Node — Main Application
 * Target: STM32G071RBT6
 *
 * Firmware for a single bunk segment sensor node.
 * - Initializes 4× VL53L7CX ToF sensors via I2C
 * - Responds to Modbus RTU queries from Opta gateway via RS485
 * - Participates in daisy-chain auto-addressing at boot
 * - Measures feed level every 500ms, updates Modbus registers
 */

#include "stm32g0xx_hal.h"
#include "pin_config.h"
#include "modbus_slave.h"
#include "vl53l7cx_driver.h"
#include "auto_address.h"

/* ── Firmware Version ── */
#define FW_VERSION_MAJOR    1
#define FW_VERSION_MINOR    0

/* ── Timing ── */
#define MEASUREMENT_INTERVAL_MS   500
#define LED_BLINK_FAST_MS          100
#define LED_BLINK_SLOW_MS          1000
#define ADDR_TIMEOUT_MS            30000  /* Max time to wait for addressing */

/* ── Peripheral Handles ── */
static UART_HandleTypeDef  huart2;      /* RS485 */
static I2C_HandleTypeDef   hi2c1;       /* CAM1 + CAM2 */
static I2C_HandleTypeDef   hi2c2;       /* CAM3 + CAM4 */
static TIM_HandleTypeDef   htim7;       /* Modbus 3.5-char timer */

/* ── State ── */
static volatile uint32_t tick_ms = 0;
static uint32_t boot_time_s = 0;
static uint8_t  num_sensors_ok = 0;

/* ── Forward Declarations ── */
static void SystemClock_Config(void);
static void GPIO_Init(void);
static void I2C1_Init(void);
static void I2C2_Init(void);
static void USART2_RS485_Init(void);
static void TIM7_Init(void);
static void LED_Set(bool on);
static void LED_Toggle(void);
static void update_registers(const node_measurement_t *m);

/* ============================================================
   MAIN
   ============================================================ */

int main(void)
{
    HAL_Init();
    SystemClock_Config();

    /* Initialize peripherals */
    GPIO_Init();
    I2C1_Init();
    I2C2_Init();
    USART2_RS485_Init();
    TIM7_Init();

    /* Initialize modules */
    addr_chain_init();
    modbus_init();

    /* Try to load previously saved address from flash */
    uint8_t saved_addr = addr_load_from_flash();
    if (saved_addr > 0 && saved_addr <= MODBUS_MAX_ADDRESS) {
        modbus_set_address(saved_addr);
    }

    /* Initialize ToF sensors */
    LED_Set(true);
    num_sensors_ok = tof_init();
    LED_Set(false);

    /* Set firmware version register */
    modbus_set_register(REG_FW_VERSION,
        (FW_VERSION_MAJOR << 8) | FW_VERSION_MINOR);

    boot_time_s = HAL_GetTick() / 1000;

    uint32_t last_measurement = 0;
    uint32_t last_led_toggle = 0;

    /* ── Main Loop ── */
    while (1) {
        uint32_t now = HAL_GetTick();

        /* Process incoming Modbus frames */
        modbus_process();

        /* Periodic measurement */
        if (now - last_measurement >= MEASUREMENT_INTERVAL_MS) {
            last_measurement = now;

            if (num_sensors_ok > 0) {
                tof_start_measurement();
            }
        }

        /* Check if measurement data is ready */
        if (tof_data_ready()) {
            node_measurement_t result;
            tof_read_results(&result);
            update_registers(&result);
        }

        /* Update uptime */
        uint32_t uptime_s = (now / 1000) - boot_time_s;
        modbus_set_register(REG_UPTIME_HI, (uint16_t)(uptime_s >> 16));
        modbus_set_register(REG_UPTIME_LO, (uint16_t)(uptime_s & 0xFFFF));

        /* Status LED pattern */
        uint32_t blink_rate = (modbus_get_address() == MODBUS_ADDR_UNASSIGNED)
                              ? LED_BLINK_FAST_MS : LED_BLINK_SLOW_MS;
        if (now - last_led_toggle >= blink_rate) {
            last_led_toggle = now;
            LED_Toggle();
        }
    }
}

/* ============================================================
   MODBUS CALLBACKS
   ============================================================ */

void on_address_assigned(uint8_t addr)
{
    modbus_set_address(addr);
    addr_chain_enable_next();  /* Enable next node in daisy chain */
}

void on_addressing_complete(void)
{
    uint8_t addr = modbus_get_address();
    if (addr > 0) {
        addr_save_to_flash(addr);
    }
}

void on_full_data_request(void)
{
    /* Full 8×8 zone data request — handled in modbus_process() */
}

/* ============================================================
   REGISTER UPDATE
   ============================================================ */

static void update_registers(const node_measurement_t *m)
{
    modbus_set_register(REG_STATUS,    m->status_bits);
    modbus_set_register(REG_CAM1_FILL, m->cameras[0].fill_pct_x10);
    modbus_set_register(REG_CAM2_FILL, m->cameras[1].fill_pct_x10);
    modbus_set_register(REG_CAM3_FILL, m->cameras[2].fill_pct_x10);
    modbus_set_register(REG_CAM4_FILL, m->cameras[3].fill_pct_x10);
    modbus_set_register(REG_AVG_FILL,  m->avg_fill_x10);
    modbus_set_register(REG_VARIANCE,  m->variance_x10);
    modbus_set_register(REG_CONFIDENCE, m->confidence);

    /* Read internal temperature sensor */
    /* TODO: ADC read of internal temp sensor → REG_NODE_TEMP */
}

/* ============================================================
   PERIPHERAL INITIALIZATION
   ============================================================ */

static void SystemClock_Config(void)
{
    /* Configure HSI16 → PLL → 64 MHz SYSCLK */
    RCC_OscInitTypeDef osc = {0};
    osc.OscillatorType = RCC_OSCILLATORTYPE_HSI;
    osc.HSIState = RCC_HSI_ON;
    osc.HSICalibrationValue = RCC_HSICALIBRATION_DEFAULT;
    osc.PLL.PLLState = RCC_PLL_ON;
    osc.PLL.PLLSource = RCC_PLLSOURCE_HSI;
    osc.PLL.PLLM = RCC_PLLM_DIV1;
    osc.PLL.PLLN = 8;
    osc.PLL.PLLP = RCC_PLLP_DIV2;
    osc.PLL.PLLR = RCC_PLLR_DIV2;
    HAL_RCC_OscConfig(&osc);

    RCC_ClkInitTypeDef clk = {0};
    clk.ClockType = RCC_CLOCKTYPE_HCLK | RCC_CLOCKTYPE_SYSCLK |
                    RCC_CLOCKTYPE_PCLK1;
    clk.SYSCLKSource = RCC_SYSCLKSOURCE_PLLCLK;
    clk.AHBCLKDivider = RCC_SYSCLK_DIV1;
    clk.APB1CLKDivider = RCC_HCLK_DIV1;
    HAL_RCC_ClockConfig(&clk, FLASH_LATENCY_2);
}

static void GPIO_Init(void)
{
    __HAL_RCC_GPIOA_CLK_ENABLE();
    __HAL_RCC_GPIOB_CLK_ENABLE();
    __HAL_RCC_GPIOC_CLK_ENABLE();

    GPIO_InitTypeDef gpio = {0};

    /* Status LED — push-pull output */
    gpio.Pin = LED_PIN;
    gpio.Mode = GPIO_MODE_OUTPUT_PP;
    gpio.Pull = GPIO_NOPULL;
    gpio.Speed = GPIO_SPEED_FREQ_LOW;
    HAL_GPIO_Init(LED_PORT, &gpio);

    /* VL53L7CX LPn pins — push-pull output, start LOW (sensors disabled) */
    gpio.Pin = CAM1_LPN_PIN | CAM2_LPN_PIN | CAM3_LPN_PIN | CAM4_LPN_PIN;
    gpio.Mode = GPIO_MODE_OUTPUT_PP;
    gpio.Pull = GPIO_NOPULL;
    HAL_GPIO_Init(GPIOB, &gpio);
    HAL_GPIO_WritePin(GPIOB, CAM1_LPN_PIN | CAM2_LPN_PIN |
                             CAM3_LPN_PIN | CAM4_LPN_PIN, GPIO_PIN_RESET);
}
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

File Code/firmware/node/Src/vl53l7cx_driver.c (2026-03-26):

/**
 * BunkScanner Node — VL53L7CX ToF Sensor Driver
 *
 * Manages 4× VL53L7CX multizone ToF sensors across two I2C buses.
 * - Sequential LPn-based I2C address assignment at init
 * - 8×8 zone ranging with fill percentage computation
 * - Split across I2C1 (CAM1+CAM2) and I2C2 (CAM3+CAM4)
 *
 * Note: This driver wraps the ST VL53L7CX ULD (Ultra Lite Driver).
 * The actual ULD source files must be placed in Code/firmware/node/Drivers/.
 */

#include "vl53l7cx_driver.h"
#include "pin_config.h"
#include "stm32g0xx_hal.h"
#include <string.h>

/* ── External HAL access ── */
extern I2C_HandleTypeDef *get_i2c_handle(uint8_t bus);

/* ── Sensor I2C Addresses ── */
static const uint8_t cam_addrs[NUM_CAMERAS] = {
    CAM1_I2C_ADDR, CAM2_I2C_ADDR, CAM3_I2C_ADDR, CAM4_I2C_ADDR
};

/* ── I2C Bus Assignment: CAM1,CAM2 → bus 0 (I2C1), CAM3,CAM4 → bus 1 (I2C2) ── */
static const uint8_t cam_bus[NUM_CAMERAS] = { 0, 0, 1, 1 };

/* ── LPn Pin Mapping ── */
static GPIO_TypeDef *const lpn_ports[NUM_CAMERAS] = {
    CAM1_LPN_PORT, CAM2_LPN_PORT, CAM3_LPN_PORT, CAM4_LPN_PORT
};
static const uint16_t lpn_pins[NUM_CAMERAS] = {
    CAM1_LPN_PIN, CAM2_LPN_PIN, CAM3_LPN_PIN, CAM4_LPN_PIN
};

/* ── Per-Camera State ── */
typedef struct {
    bool             initialized;
    bool             ranging_active;
    sensor_health_t  health;
    uint16_t         zone_distances[VL53L7CX_RESOLUTION];
    uint16_t         fill_pct_x10;
    uint8_t          valid_zones;
} cam_state_t;

static cam_state_t cameras[NUM_CAMERAS];
static volatile bool measurement_pending = false;
static volatile bool data_ready_flag = false;

/* ── I2C Low-Level Helpers ── */

static HAL_StatusTypeDef i2c_write_reg16(uint8_t bus, uint8_t dev_addr,
                                          uint16_t reg, uint8_t *data, uint16_t len)
{
    I2C_HandleTypeDef *hi2c = get_i2c_handle(bus);
    return HAL_I2C_Mem_Write(hi2c, dev_addr << 1, reg,
                             I2C_MEMADD_SIZE_16BIT, data, len, 100);
}

static HAL_StatusTypeDef i2c_read_reg16(uint8_t bus, uint8_t dev_addr,
                                         uint16_t reg, uint8_t *data, uint16_t len)
{
    I2C_HandleTypeDef *hi2c = get_i2c_handle(bus);
    return HAL_I2C_Mem_Read(hi2c, dev_addr << 1, reg,
                            I2C_MEMADD_SIZE_16BIT, data, len, 100);
}

/* ── Sensor Address Reprogramming ── */

static bool reprogram_i2c_address(uint8_t bus, uint8_t new_addr)
{
    /*
     * VL53L7CX address change procedure:
     * Write new address (7-bit) to register 0x0001 on default address.
     */
    uint8_t addr_byte = new_addr;
    HAL_StatusTypeDef status = i2c_write_reg16(bus, VL53L7CX_DEFAULT_ADDR,
                                                0x0001, &addr_byte, 1);
    return (status == HAL_OK);
}

/* ── Sensor Initialization ── */

static bool init_single_sensor(uint8_t idx)
{
    uint8_t bus = cam_bus[idx];

    /* Step 1: Enable sensor via LPn pin */
    HAL_GPIO_WritePin(lpn_ports[idx], lpn_pins[idx], GPIO_PIN_SET);
    HAL_Delay(10);  /* Wait for sensor to boot */

    /* Step 2: Check sensor responds at default address */
    I2C_HandleTypeDef *hi2c = get_i2c_handle(bus);
    if (HAL_I2C_IsDeviceReady(hi2c, VL53L7CX_DEFAULT_ADDR << 1, 3, 100) != HAL_OK) {
        cameras[idx].health = SENSOR_OFFLINE;
        return false;
    }

    /* Step 3: Reprogram to unique address */
    if (!reprogram_i2c_address(bus, cam_addrs[idx])) {
        cameras[idx].health = SENSOR_FAULT;
        return false;
    }
    HAL_Delay(5);

    /* Step 4: Verify sensor responds at new address */
    if (HAL_I2C_IsDeviceReady(hi2c, cam_addrs[idx] << 1, 3, 100) != HAL_OK) {
        cameras[idx].health = SENSOR_FAULT;
        return false;
    }

    /* Step 5: Configure sensor for 8×8 resolution, continuous ranging */
    /*
     * TODO: Replace with actual VL53L7CX ULD initialization calls:
     *   vl53l7cx_init(&dev[idx]);
     *   vl53l7cx_set_resolution(&dev[idx], VL53L7CX_RESOLUTION_8X8);
     *   vl53l7cx_set_ranging_frequency_hz(&dev[idx], 5);  // 5Hz
     *   vl53l7cx_set_ranging_mode(&dev[idx], VL53L7CX_RANGING_MODE_CONTINUOUS);
     */

    cameras[idx].initialized = true;
    cameras[idx].health = SENSOR_OK;
    return true;
}

/* ── Fill Percentage Calculation ── */

static void compute_fill(uint8_t idx)
{
    cam_state_t *cam = &cameras[idx];
    if (!cam->initialized || cam->health >= SENSOR_FAULT) {
        cam->fill_pct_x10 = 0;
        cam->valid_zones = 0;
        return;
    }

    uint32_t total_fill = 0;
    uint8_t valid = 0;

    for (uint8_t z = 0; z < VL53L7CX_RESOLUTION; z++) {
        uint16_t dist_mm = cam->zone_distances[z];

        /* Filter out invalid readings (0 or > 2× bunk depth) */
        if (dist_mm == 0 || dist_mm > BUNK_DEPTH_MM * 2) continue;

        /* Clamp to bunk depth */
        if (dist_mm > BUNK_DEPTH_MM) dist_mm = BUNK_DEPTH_MM;

        /* Fill % = (depth - distance) / depth × 100
         * distance = 0 → full (100%), distance = depth → empty (0%) */
        uint16_t fill = ((BUNK_DEPTH_MM - dist_mm) * 1000) / BUNK_DEPTH_MM;
        total_fill += fill;
        valid++;
    }

    cam->valid_zones = valid;
    if (valid > 0) {
        cam->fill_pct_x10 = (uint16_t)(total_fill / valid);
    } else {
        cam->fill_pct_x10 = 0;
        cam->health = SENSOR_DEGRADED;
    }
}

/* ============================================================
   PUBLIC API
   ============================================================ */

uint8_t tof_init(void)
{
    memset(cameras, 0, sizeof(cameras));

    /*
     * Sequential LPn-based address assignment:
     * Enable one sensor at a time, reprogram its I2C address,
     * then enable the next. This avoids address conflicts since
     * all sensors share the same default address.
     */
    uint8_t ok_count = 0;
    for (uint8_t i = 0; i < NUM_CAMERAS; i++) {
        if (init_single_sensor(i)) {
            ok_count++;
        }
    }

    return ok_count;
}
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

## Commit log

2026-03-19 Add 3D models, datasheets and move reference images
    Add design assets and research files: new 3D CAD files (Design/3D/Bunk 1.ipt, Bunker_scan.ipj and a large vl53l7cx-carrier-model.step), Bill of Materials spreadsheet, datasheets/manuals, and proposal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
    [Bill of Materials.xlsx, Bunk 1.ipt]
2026-03-19 Organize documentation and add comprehensive 5-year strategic plan
    - Centralized all .md documentation into docs/ folder
    - Added comprehensive 5-year strategic plan (2026-2031)
    - Created documentation index with implementation status
    - Added partnership evolution and exit strategy details
    - Included financial projections: $500K → $70M revenue trajectory
    - Updated main README with development status and doc references
    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
2026-03-24 3D design - layout configuration development
    [00 INSTALLATION.0001.iam, 00 INSTALLATION.iam, vl53l7cx-FOV.0001.ipt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]
